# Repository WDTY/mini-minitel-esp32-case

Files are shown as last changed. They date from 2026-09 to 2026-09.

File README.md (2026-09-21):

# Mini Minitel ESP32 case

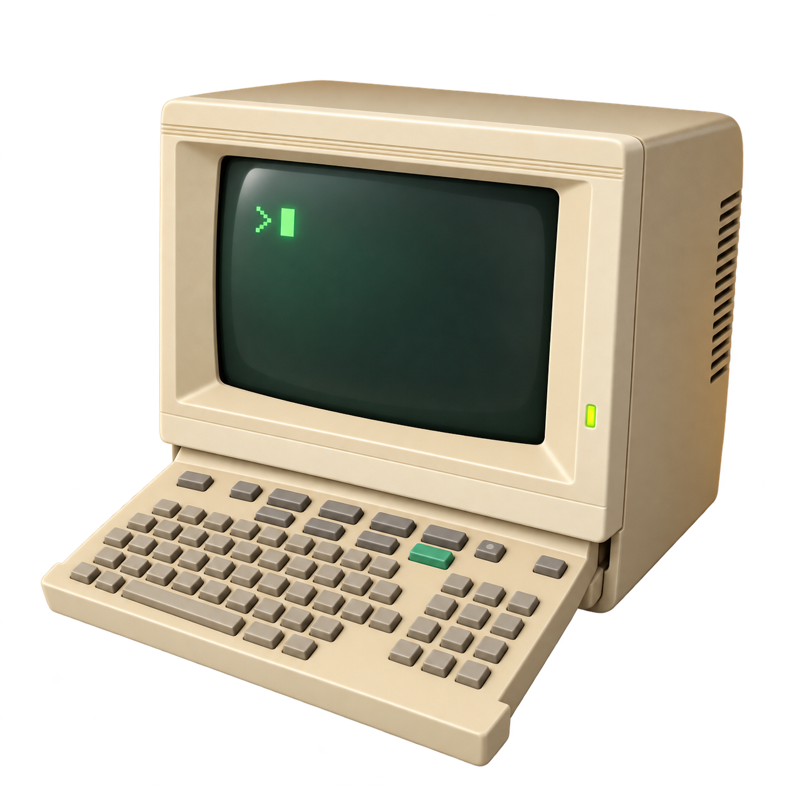
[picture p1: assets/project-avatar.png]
Mini Minitel project avatar


A printable Minitel-shaped enclosure for the
[iodeo ESP Minitel V2](https://github.com/iodeo/Minitel-ESP32) JST cable-to-DIN board.

## Current design: complete three-part v0.5

v0.5 is the complete avatar-inspired miniature Minitel. It prints as three
parts: a hollow cabinet, a separate multicolour keyboard and one removable
ESP32 bay. The external design uses no geometry from the iodeo electronics
enclosure.

Connect JST first, slide the PCB into the bay's edge guides, form the measured
60 mm cable turn and slide the loaded bay into the lower rear of the Minitel.
USB-C and the protruding flexible RESET pad remain accessible at the back. The
DIN plug lays into an open-top notch and never passes through a printed hole.

- [Complete Minitel case STL](stl/v0.5/minitel_case_v0.5.stl)
- [Separate multicolour keyboard STL](stl/v0.5/minitel_keyboard_v0.5.stl)
- [Removable ESP32 bay STL](stl/v0.5/minitel_esp32_bay_v0.5.stl)
- [Dimensions, assembly route, K2 settings and multicolour guide](docs/V0.5-DESIGN.md)
- [Editable OpenSCAD source](src/minitel_v05.scad)

The case is exported flat on its rear. This puts the dark CRT and green
prompt/cursor/lens in the final bounded layers. The keyboard is a separate
flat-bottomed print, so its grey keys and green Enter key do not cause colour
changes throughout the much larger cabinet print.

The CRT face is a shallow compound curve rather than a flat plate. Its centre
bulges forward while the perimeter stays recessed, and the beige inner bezel
funnels inward toward that recessed edge to match the project avatar.

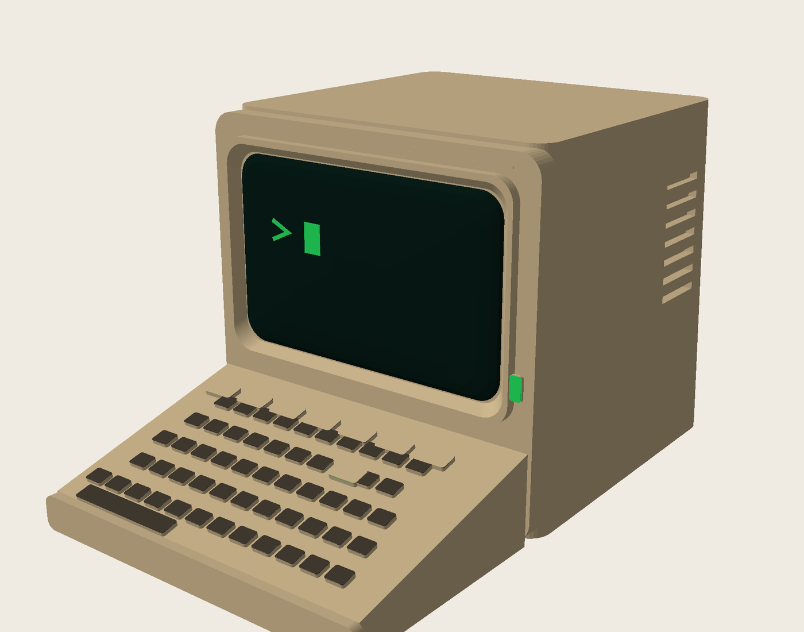
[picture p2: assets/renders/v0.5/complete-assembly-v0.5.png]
Complete multicolour v0.5 assembly

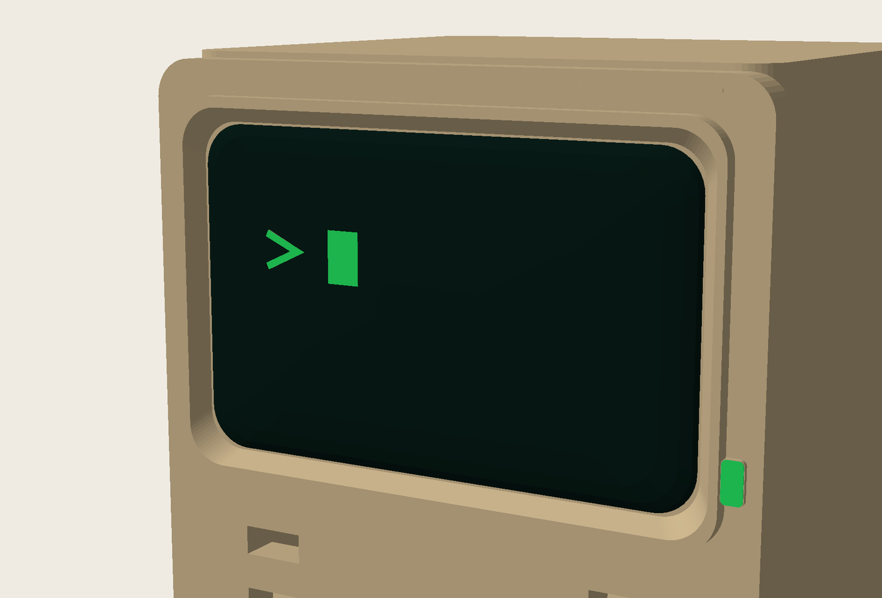
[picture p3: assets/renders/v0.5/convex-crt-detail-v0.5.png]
Convex CRT glass and inward-running bezel

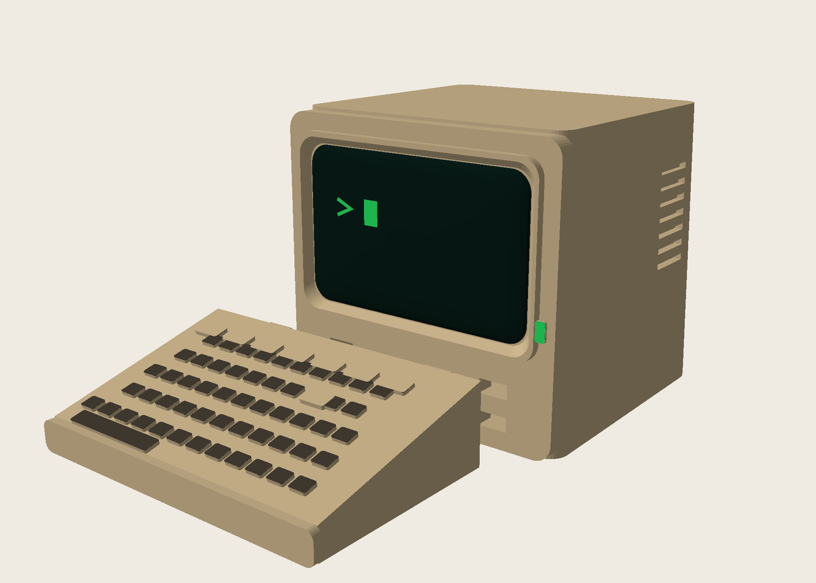
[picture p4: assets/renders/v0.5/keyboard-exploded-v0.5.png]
Separate keyboard and four locating tongues

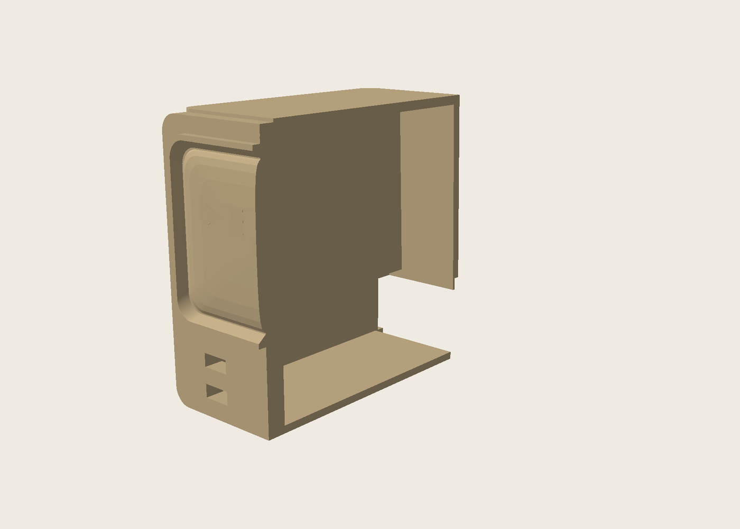
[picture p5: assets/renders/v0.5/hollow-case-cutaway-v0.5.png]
Hollow cabinet, bay guides and print bridge ribs

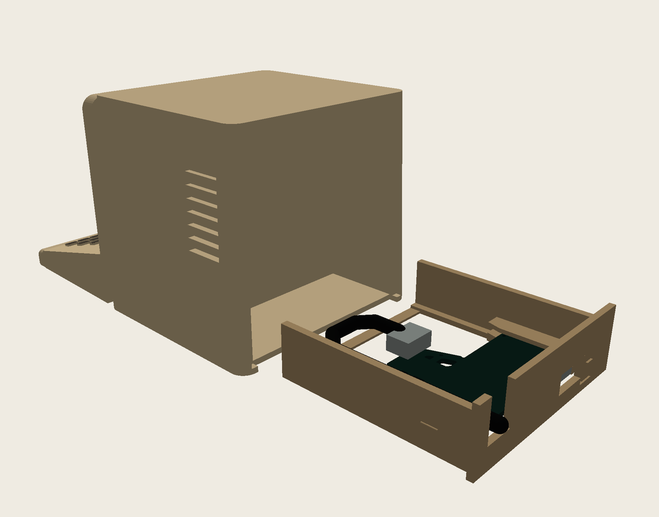
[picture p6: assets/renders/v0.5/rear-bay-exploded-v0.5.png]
Loaded bay behind the lower rear opening

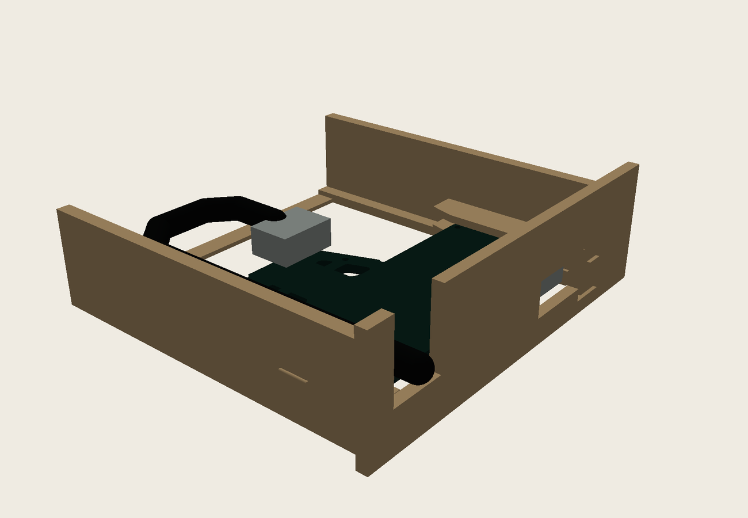
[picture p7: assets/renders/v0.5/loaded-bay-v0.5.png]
ESP32, connected cable and U-turn in the bay

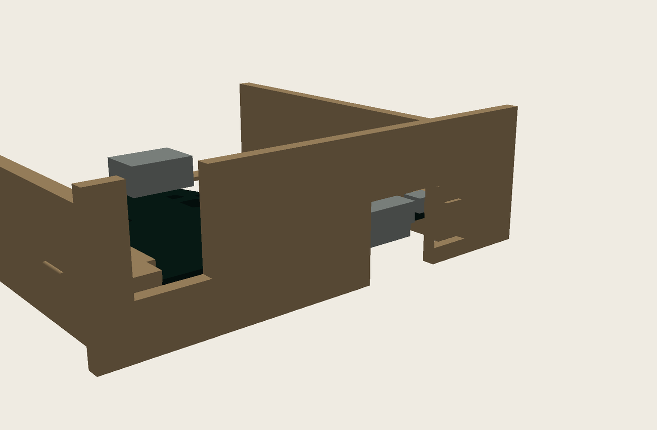
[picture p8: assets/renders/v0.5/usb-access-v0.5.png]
Bottom-open USB-C access at the rear face

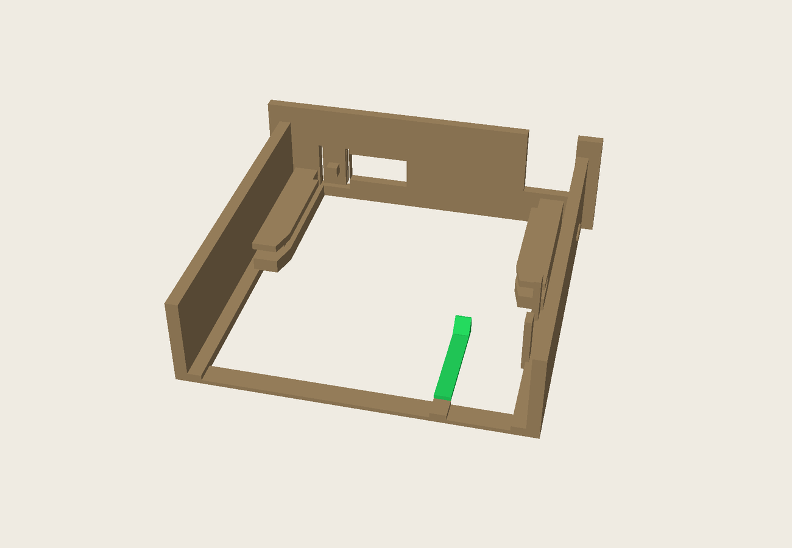
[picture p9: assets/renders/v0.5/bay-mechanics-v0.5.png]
U-rails, front bridge and PCB retention latch


All three parts contain an enclosed `WDTY v0.5` watermark spanning three
0.20 mm layers. The cabinet is a true hollow shell rather than a solid infill
volume. Thin U-guides locate the bay and three permanent 1.2 mm bridge ribs
reduce the rear-down front-wall bridge to 24 mm. The curved CRT backing
overlaps the cabinet by 3.2 mm, so it forms one continuous structure without
a slit.

This remains a mechanical prototype rather than a fully fit-verified release.
A physical ESP Minitel V2 test confirms the PCB/rail fit and cable route. That
test also exposed a USB-C window that sat too high; the rear face now uses a
bottom-open service notch. The bay has a releasable PCB latch, a positive
flange shoulder and open guides for the measured 4.3 mm cable. Those guides
are not hard strain relief. Plug clearance, latch force and RESET travel still
need verification after printing the corrected bay.
See the mechanical audit before printing: a collision-free reference model
alone does not prove physical fit.

## Repository layout

- [`src/`](src/): editable v0.5 OpenSCAD source.
- [`stl/v0.5/`](stl/v0.5/): the three current printable parts.
- [`docs/`](docs/): v0.5 design notes and PCB-reference provenance.
- [`assets/renders/v0.5/`](assets/renders/v0.5/): current CAD renders.
- [`assets/photos/`](assets/photos/): owner-supplied hardware photographs.
- [`reference/`](reference/): PCB inspection mesh and unchanged iodeo references.
- [`tools/`](tools/): Gerber extraction, validation and render scripts.
- [`archive/`](archive/): superseded development files, intentionally omitted
  from this current-version README.

## Editing and exporting

Open [`src/minitel_v05.scad`](src/minitel_v05.scad) in OpenSCAD and select
`case`, `keyboard`, `bay`, `case_assembly` or `assembly` with the `part`
parameter. See the v0.5 design notes for reproducible export, render and
clearance-check commands.

## Attribution and license

Hardware reference: [Louis H./iodeo](https://github.com/iodeo/Minitel-ESP32)
and [Hackaday project](https://hackaday.io/project/180473-minitel-esp32).
This derivative case is licensed under [CC BY-SA 4.0](LICENSE).
Contributions and measured fit reports are welcome.

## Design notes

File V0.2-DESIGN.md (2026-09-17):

# v0.2 proportion study

> Physical-test update: the PCB locating pins and USB-C position do not align
> reliably with the real JST-board. Do not force the PCB or print another v0.2
> body. The corrective design should preserve the printed shell by using a
> separate internal carrier and a shallow inset/snap front.

v0.1 proved the PCB mounting concept, but its `60 x 60 x 34 mm` cabinet and
13 mm keyboard projection read more like an arcade cabinet than an open
Minitel.

The v0.2 work-in-progress uses a new envelope:

| Feature | v0.1 | v0.2 WIP |
| --- | ---: | ---: |
| Cabinet width | 60 mm | 68 mm |
| Cabinet height | 60 mm | 60 mm |
| Cabinet depth | 34 mm | 58 mm |
| Keyboard projection | 13 mm | 38 mm |
| Screen insert | 41 x 22.2 mm | 51.2 x 28.6 mm |

The target is derived independently from owner-supplied photographs and the
published approximate real-machine envelope of `250 x 220 x 260 mm`. The
downloadable Sketchfab reference model was not imported or reused because its
page carries a NoAI restriction.

Research references:

- <https://hackaday.com/2022/02/16/teardown-alcatel-telic-1-minitel-terminal/>
- <https://sketchfab.com/3d-models/minitel-1982-france-864f54ce4e1f41abab0688b88a45babf>
- <https://minitel.us/terminals>

v0.2 was published as a test prototype. Its fit-critical PCB coordinates,
USB-C opening, RESET access and JST cable exit were based on the official iodeo
v2.2 Gerber/drill files and photographs, but the physical test demonstrated
that the coordinate transformation was not reliable enough for the real board.

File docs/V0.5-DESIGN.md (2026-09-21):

# v0.5 complete Minitel case

v0.5 is a complete three-part enclosure for the owner's populated iodeo ESP
Minitel V2 **JST** board. Its exterior follows the project's Minitel avatar;
no geometry from the iodeo electronics enclosure is used.

## Print files

Three current STL files are required:

1. `minitel_case_v0.5.stl` — hollow Minitel cabinet with fixed CRT front,
   vents, bridge ribs and lower rear bay opening; exported on its flat rear.
2. `minitel_keyboard_v0.5.stl` — separate flat-bottomed keyboard, normal keys,
   green Enter-key boundary, front lip and four locating tongues.
3. `minitel_esp32_bay_v0.5.stl` — removable cartridge with PCB edge guides,
   60 mm cable-turn envelope, rear USB-C opening, cable guides, releasable PCB
   latch and flexible reset plunger.

The assembled case measures approximately **78 × 123 × 74 mm**, including the
open keyboard. The bay measures **70 × 66.6 × 21 mm** at its closing flange.
Every part fits comfortably on a Creality K2 build plate.

## Assembly route

1. Push the four keyboard tongues straight into the clearance pockets in the
   lower front of the cabinet. Do not glue this first physical test.
2. Connect the JST plug to the unpowered PCB before putting it in the bay.
3. From the open inner end of the bay, feed the broad USB-C edge into the two
   flared edge guides and slide the board toward the bay's rear face.
4. Lay the cable in a relaxed U: forward from the JST, around the open front of
   the bay and back along the right side. Lay the 4.3 mm cable from above into
   the two outside guides and the open-top rear notch. The 15.5 mm DIN plug
   remains outside and never has to pass through a printed hole.
5. Check that USB-C is centred in its rear opening and that the protruding
   printed reset pad moves freely.
6. The floor cantilever clicks behind the narrow JST-side PCB nose. To remove
   the PCB, press this tab downward with a small plastic tool while sliding the
   board toward the open end.
7. Slide the complete loaded bay into the opening at the lower rear of the
   Minitel until its recessed flange meets the positive cabinet shoulder. The
   shallow side beads provide light retention.

The PCB rests only in 1.0 mm edge channels. There is no snap-on board plate.

## Measured inputs and clearances

| Item | Value |
|---|---:|
| Gerber PCB envelope | 47.105 × 36.218 mm |
| Owner's measured PCB envelope | approximately 46.9 × 36.1 mm |
| Populated height | 10.4 mm |
| Reset protrusion beyond PCB edge | 1.5 mm |
| Black DIN cable diameter | 4.3 mm |
| DIN plug maximum diameter | 15.5 mm |
| PCB thickness | 1.6 mm nominal |
| PCB slot height | 2.2 mm |
| Vertical PCB clearance | 0.30 mm per side |
| Horizontal guide clearance | 0.35 mm per side |
| Case/bay sliding clearance | 0.40 mm per side |
| USB outer edge to outside of relaxed cable bend | 60 mm |
| Bay flange-to-shoulder rest clearance | 0.15 mm |

The route and exit remain open: the printed part guides the measured cable but
does not clamp or sharply bend it. The DIN plug stays outside the enclosure.

## Creality K2 baseline

- 0.4 mm nozzle and fixed 0.20 mm layers.
- PLA for the first print.
- Print all parts in their exported orientation. The case is already rotated
  with its broad rear face on Z=0; do not stand it upright.
- 3 walls, 5 top/bottom layers and 12–15% gyroid infill.
- The hollow cabinet needs no internal infill. Three permanent 1.2 mm ribs
  reduce the final front-wall bridge to 24 mm. Set bridge direction across the
  cabinet width and inspect those layers in preview before printing.
- Keep automatic support disabled inside the hollow cabinet: it would be hard
  to remove through the bay opening. The rear bay opening starts at the plate.
- Keep support out of the PCB guide slots, reset tongue and keyboard pockets.
- Do not scale the models and leave XY/hole compensation at zero for the first
  fit test.
- A brim is normally unnecessary for the rear-down case. A 3–5 mm brim is
  optional for the separate keyboard if its front corners lift.

## Multicolour treatment

STL does not store filament colours. Put the case and keyboard on separate
plates/jobs to avoid unnecessary CFS colour swaps. Use surface painting in
Creality Print or OrcaSlicer:

- Case job: warm beige cabinet, near-black-green CRT, and bright-green prompt,
  cursor and status lens. With the case rear-down these are bounded final
  layers instead of colour changes through the full cabinet height.
- Keyboard job: warm beige deck, dark grey-brown normal keys/spacebar and a
  bright-green Enter key.
- Bay job: cabinet beige or a slightly darker beige, single colour.

All coloured faces are raised or bounded so surface-fill painting can select
them without extra colour STL files.

## Hidden watermark

All three print parts contain an enclosed `WDTY v0.5` void. The void is 0.60 mm
high at Z 0.60–1.20 mm: exactly three layers with the 0.20 mm K2 baseline. It
is invisible from outside and can be found in the slicer's layer preview.
Adaptive layer height changes the layer count, so keep the first 1.4 mm at
0.20 mm when preservation of the three-layer mark matters.

## CAD verification

- All three final STL files are closed, with zero nonmanifold edges.
- The keyboard is checked at its nominal installed position and has no hard
  collision with the cabinet or its four receiver pockets.
- The exact Gerber PCB and approximate component envelopes are sampled at 49
  positions through the PCB-to-bay insertion route.
- The complete loaded bay is sampled at 71 positions through the rear case
  opening. The shallow retention beads are intentionally excluded from the
  hard-collision check because they provide the designed friction contact.
- The routed PCB/component/cable envelopes do not intersect the rigid bay.
- Both lower guide lips overlap the PCB edges by 1 mm; support is checked
  by lowering the reference PCB through the nominal 0.30 mm clearance.
- The reset plunger has 0.30 mm nominal rest clearance to the approximate
  switch envelope and contacts it with 0.50 mm inward travel. This is a rigid
  envelope test, not a flexure or switch-force simulation.
- The floor latch is clear at the installed position and catches the PCB after
  0.70 mm movement toward the open end.
- The bay flange has 0.15 mm rest clearance and contacts the cabinet shoulder
  after 0.20 mm inward overtravel.
- The measured 4.3 mm cable envelope is checked at exactly 60 mm from the
  protruding USB-C edge to the outside of its relaxed U-bend.

## Mechanical audit / revised v0.5

The cabinet is now a hollow 2.0–2.4 mm shell. Thin longitudinal U-guides retain
the bay without a solid tunnel, and three 1.2 mm ribs support the fixed front
when it is printed rear-down. The front fascia overlaps the cabinet by 3.2 mm;
the bezel and CRT surface also have positive overlap, so the screen assembly
cannot become a detached or coplanar shell. Six nested screen profiles form a
shallow compound CRT bulge, while the bezel aperture widens toward the viewer
to create the avatar's inward-running surround. The glass centre remains just
behind the beige bezel face, protecting it during handling.

The original lower guide lips ended outside the PCB. They now extend inward
to match the upper lips, including the flared entrance. The cartridge also has
a four-layer structural front bridge below the underside component envelope,
an accessible PCB retention cantilever and open outside cable guides. The rear
trapezoidal opening is closed above the cartridge, and a two-stage body opening
plus shallow flange recess provides a defined insertion stop. Collision tests
use the complete case rather than only its core and fail on OpenSCAD errors.

Correction to the discussion: there were no duplicated PCB rails in the
case source; that diagnosis resulted from misreading a module boundary.

Physical testing confirms that the ESP Minitel V2 board enters and sits in the
edge guides with its connected JST lead. The first print also showed that the
USB-C connector sat below the enclosed rear window. The corrected design uses
a bottom-open service notch and checks a conservative plug-access envelope.

Remaining unverified constraints: the component envelopes are approximations
and the PCB thickness is nominal. In particular, verify solder joints along
the 1 mm edge-contact strips, USB plug insertion depth, actual switch force/travel,
PLA latch force and cable stiffness before considering this mechanically
validated. The cable guides intentionally do not provide hard strain relief;
do not use either cable to pull the cartridge or PCB. These are prototype
limitations, not passed physical tests or a guaranteed fit.

Rebuild and check from the repository root:

```sh
openscad --export-format binstl -D 'part="case"' -o stl/v0.5/minitel_case_v0.5.stl src/minitel_v05.scad
openscad --export-format binstl -D 'part="keyboard"' -o stl/v0.5/minitel_keyboard_v0.5.stl src/minitel_v05.scad
openscad --export-format binstl -D 'part="bay"' -o stl/v0.5/minitel_esp32_bay_v0.5.stl src/minitel_v05.scad
python3 tools/check_v05_clearance.py
python3 tools/review_v05.py
```

Renders demonstrate the modelled route; the first physical print remains the
authority for filament shrinkage, cable stiffness and tactile-button travel.

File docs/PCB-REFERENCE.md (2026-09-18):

# PCB reference used for v0.3 renders

Source: iodeo/Minitel-ESP32 commit
`39c49b8462b46dfb7da84c08aecdd48e5c52a224`,
[`hardware/Gerber_minitel_esp32_v2.2.zip`](https://github.com/iodeo/Minitel-ESP32/blob/39c49b8462b46dfb7da84c08aecdd48e5c52a224/hardware/Gerber_minitel_esp32_v2.2.zip).
Attribution: Louis H./iodeo, CC BY-SA 4.0.

`tools/build_pcb_reference.py` reads BoardOutline.GKO and the T04 mounting holes in
Drill_NPTH.DRL. It preserves the outer contour and four internal cutouts.
Circular arcs are sampled at at most 0.08 mm along the arc; exported endpoints
are joined within 0.025 mm. This is a sampled CAD reference, not an exact solid
model of the populated board. Gerber extents: 36.220 x 47.105 mm in the chosen
orientation; five nominal 1.143 mm mounting holes. PCB thickness is assumed 1.60 mm.

The orientation is chosen with the connector wing left, the antenna end down
and the USB/reset edge right, based on the upstream 3D view. Position uses the
current carrier parameters: x shift 10 mm, bottom z=6 mm, PCB y=8.80..10.40 mm.
This placement is an inspection hypothesis, not a measured physical fit.

## Findings

The previous rectangular PCB proxy hid the narrow lower section and sloping
shoulders. The replacement carrier now follows the Gerber outer route, supports
all five holes and captures the real top and bottom edges. Its separate legacy
sockets preserve the already printed v0.2 body.

Components, solder joints, connector bodies, cable bending space and button
travel are not reconstructed here. USB-C plug reach and reset operation remain
unverified. The reference also needs dimensional comparison against the owner's
physical JST-equipped board before claiming compatibility.

The complete exterior uses the actual current carrier/lid/keyboard/reset meshes
and the archived v0.2 body, screen and accent inserts.

## Reproduce

Requires Python with NumPy/Pillow, OpenSCAD, and DejaVu Sans for image captions.

```sh
python tools/build_pcb_reference.py /path/to/Gerber_minitel_esp32_v2.2.zip
openscad --export-format binstl -o reference/pcb_reference.stl src/render_reference.scad
python tools/render_v03_readme.py
```

The exploded view moves the board 20 mm forward only for visibility. All images
are software renders of meshes, not generated concept illustrations.

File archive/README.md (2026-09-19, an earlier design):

# Archived prototypes

These versions are retained for reference, not as current print recommendations.

- [v0.1](v0.1/): first experimental meshes and previews.
- [v0.2](v0.2/): historical meshes, renders, design notes and OpenSCAD source.
  Physical testing revealed PCB mounting and service-opening alignment problems.
- [v0.3](v0.3/): attempted v0.2-compatible carrier and lid; fit was not established.
- [v0.4](v0.4/): donor-cassette prototype rejected after the populated JST board
  proved too wide, high and deep for the upstream enclosure.
- [development/v0.5-rear-bay-fixture](development/v0.5-rear-bay-fixture/):
  intermediate open guide fixture used to validate the edge-slot and cable
  routing concept before it was integrated into the complete two-part v0.5.

Each version keeps its source, STL files, renders and version notes together.
The v0.3 and v0.4 sources still import the archived v0.2 body modules.

The v0.2 README is historical documentation; follow the root README for current status.

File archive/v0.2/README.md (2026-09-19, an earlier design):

# Mini Minitel ESP32 case — historical v0.2 documentation

> Archived reference only. See the [current README](../../README.md) for status.

Mini Minitel project avatar

A small, printable Minitel-shaped enclosure for the
[iodeo ESP Minitel V2](https://github.com/iodeo/Minitel-ESP32) board with the
JST cable-to-DIN connector.

The v0.2 test model deliberately follows the project avatar: a rounded CRT
cabinet, recessed dark screen, top ribs, open sloping keyboard, green Enter key
and status light, and cabinet vents on the right side.

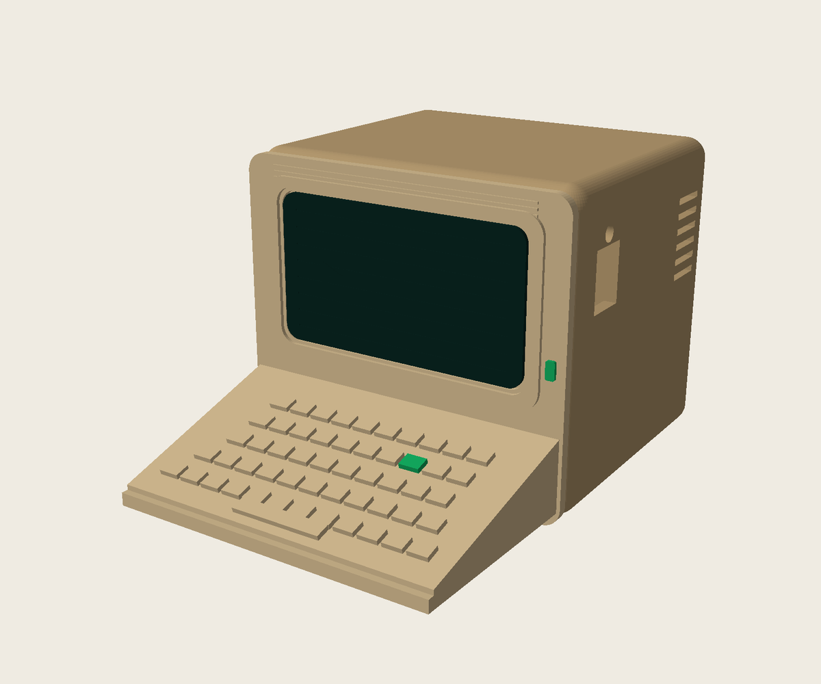
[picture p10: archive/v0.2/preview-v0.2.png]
Three-quarter right-front render of the proportionally rebuilt v0.2 enclosure


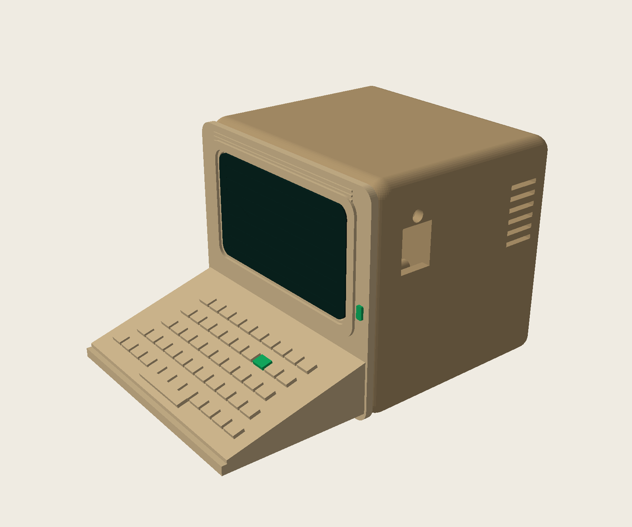
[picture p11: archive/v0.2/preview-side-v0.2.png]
Elevated right-front render showing the deeper CRT cabinet and service openings


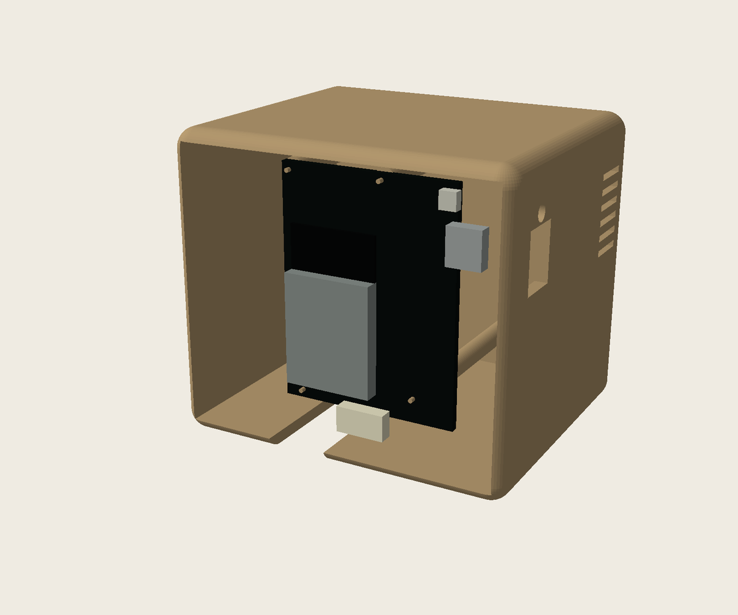
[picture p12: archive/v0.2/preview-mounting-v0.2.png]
Open-front mounting render showing the PCB orientation intended by v0.2


The ESP32 PCB is mounted vertically behind the faux screen. The JST lead exits
through the bottom. USB-C has its own plug-sized side opening and RESET has a
separate protected pinhole. The DIN connector and cable stay outside the
enclosure, so the case does not hang directly from the Minitel port.

## Target hardware

The enclosure targets this JST cable variant. The ruler is included in the
photographs as a practical size reference.

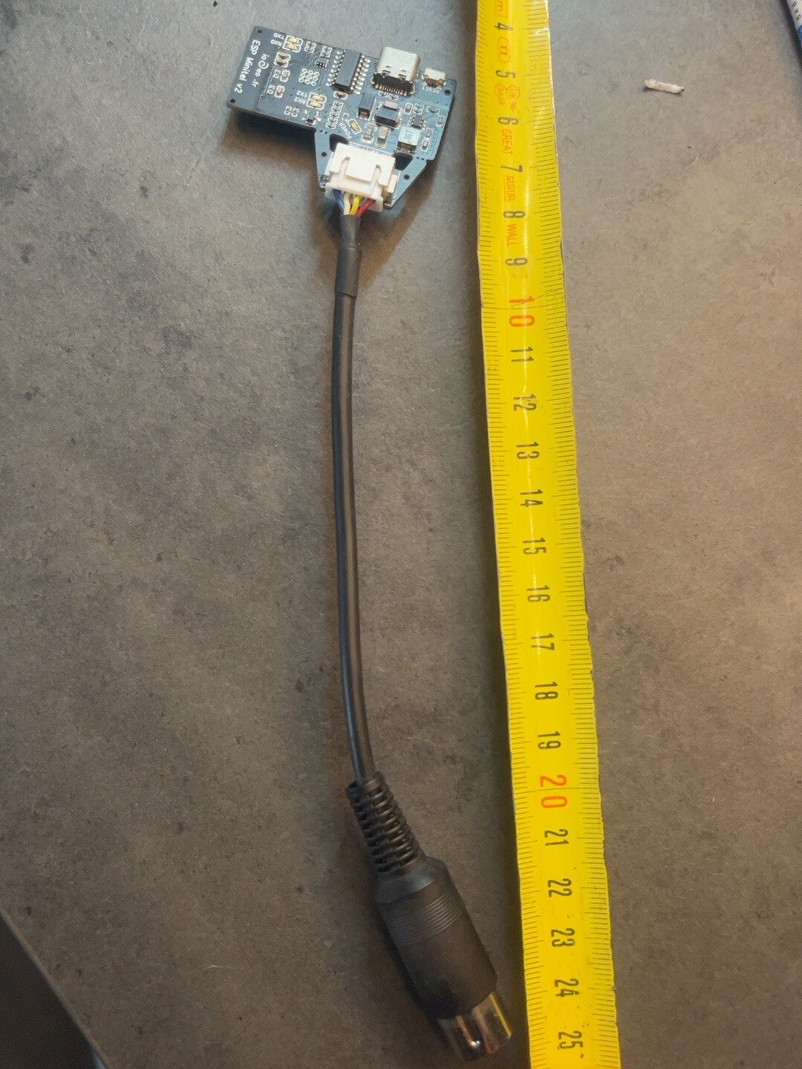
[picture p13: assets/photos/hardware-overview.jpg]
Complete ESP Minitel V2 board, cable and DIN connector


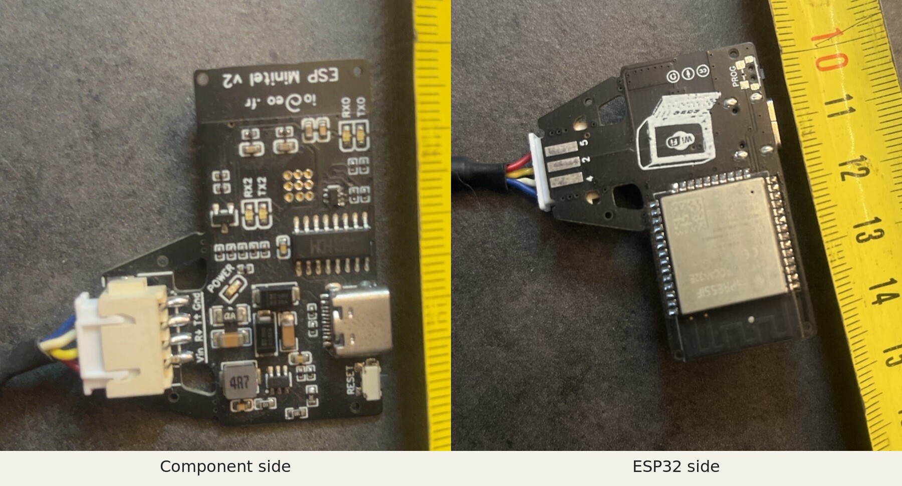
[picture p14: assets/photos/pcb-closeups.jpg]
Component and ESP32 sides of the PCB


> [!WARNING]
> The first physical **v0.2** fit test found that the PCB locating pins do not
> align reliably with the real JST-board and that the fixed USB-C opening cannot
> be reached in the intended centred position. Do not force the PCB and do not
> start a new v0.2 body print. The already printed body is being retained as the
> basis for a corrective clip-in carrier and a support-light inset front.

The first v0.3 compatibility parts are documented in
[`V0.3-COMPAT-DESIGN.md`](../v0.3/V0.3-COMPAT-DESIGN.md). They reuse an existing v0.2
body, shift the PCB on a separate edge cradle, split the front into a shallow
inset lid and removable keyboard, and replace the reset pinhole with a retained
external push button. Treat all v0.3 meshes as fit-test parts until verified on
the physical print.

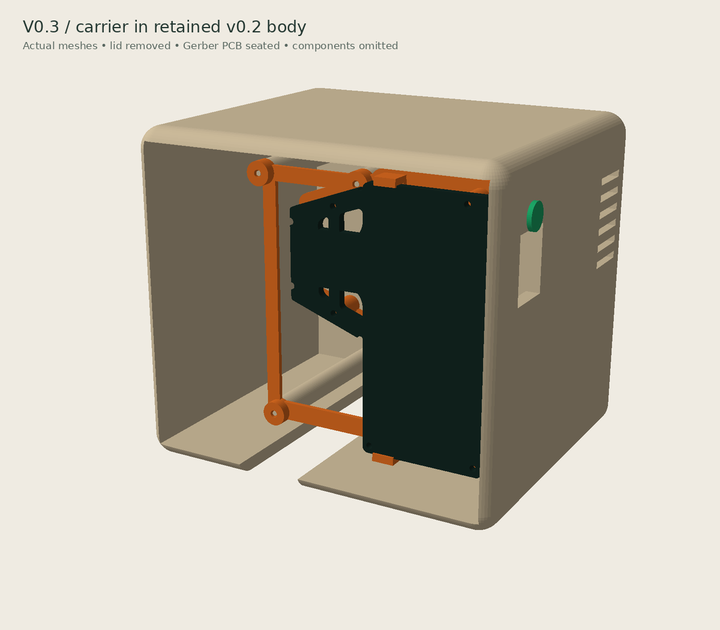
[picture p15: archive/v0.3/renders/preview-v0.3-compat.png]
v0.3 carrier and shifted PCB inside the retained v0.2 body


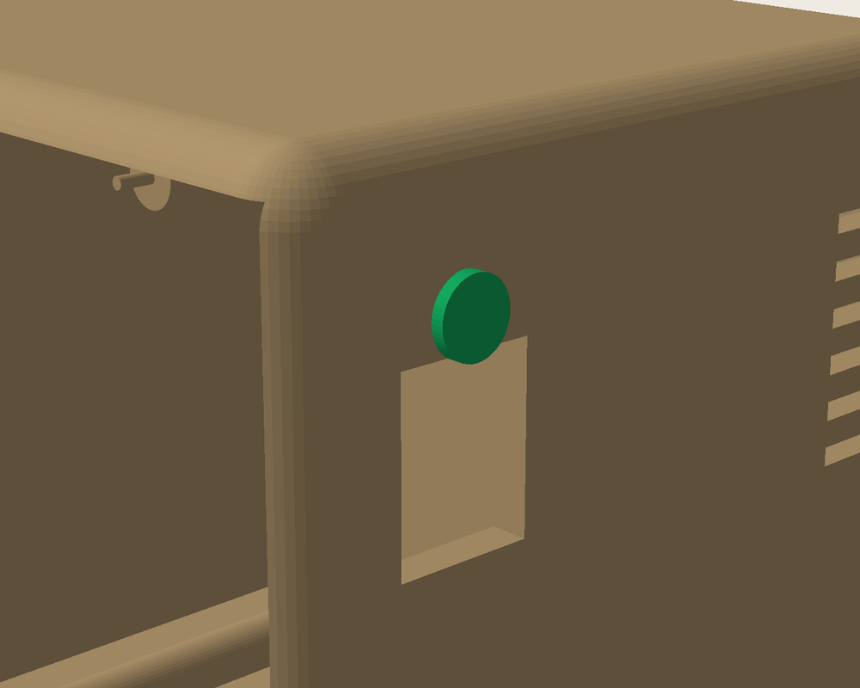
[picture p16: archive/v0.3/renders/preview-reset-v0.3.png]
Close-up render of the protruding retained reset plunger


## Features

- Parametric OpenSCAD source
- Approximately 68 × 60 × 58 mm body, rebuilt from real Minitel proportions
- Rounded CRT bezel and screen insert, top cabinet ribs and side vents
- Sloping open keyboard with a pronounced front lip
- Separate green Enter-key/status-light accent part
- Four PCB locating pins based on the official drill coordinates
- Bottom cable exit
- Separate USB-C opening with clearance for a moulded plug
- Protected RESET pinhole for a paperclip or thin tool
- Simplified printable keyboard and raised terminal-prompt detail
- Two hardware reference images, including a front/back close-up

## Repository layout

```text
archive/v0.2/                 This frozen v0.2 source, meshes and renders
archive/v0.1/                 Archived first prototype
src/                          Current v0.3 OpenSCAD sources
archive/v0.3/stl/             Archived v0.3 test meshes
docs/                         Current design and PCB-reference notes
archive/v0.3/renders/         Archived v0.3 renders
assets/photos/                Hardware overview and PCB close-ups
reference/                    Non-printable PCB inspection mesh
tools/                        Gerber extraction and rendering scripts
LICENSE                       CC BY-SA 4.0 license
```

The v0.2 assembly STL is intended for inspection only. Print the four individual
parts instead. The tiny accent STL is best assigned to green filament as a
multi-part object in OrcaSlicer; it may be omitted for a single-colour print.

## Physical v0.2 fit result

The body-only test was completed on a Creality K2. These checks remain useful
for diagnosing the corrective carrier, but v0.2 should no longer be treated as
a ready-to-print release:

1. Check that the four 0.90 mm locating pins enter the PCB holes.
2. Confirm that no rear-side component touches a support post.
3. Route the JST cable freely through the bottom opening.
4. Insert a USB-C plug fully and confirm that it does not lever against the case.
5. Confirm that RESET can be pressed through its pinhole with a thin tool.

The official drill file specifies nominal 1.143 mm holes and the locating pins
are 0.90 mm. The mismatch is positional rather than a tight-hole problem. Keep
an existing v0.2 body intact until the replacement carrier has been test-fitted.

## Suggested print settings

The model was designed for a Creality K2 with a 0.4 mm nozzle, but it does not
depend on a K2-specific feature.

| Setting | Recommendation |
| --- | --- |
| Material | PLA |
| Layer height | 0.20 mm |
| Walls | 3 |
| Top/bottom layers | 4 |
| Infill | 15% gyroid |
| Supports | Off for body/screen; build-plate-only where needed for front |
| Outer-wall speed | 60–80 mm/s for clean small lettering |

Print the body with its rear surface on the build plate and the cavity facing
up. Print the screen flat. The front may be printed on its side with a brim, or
with the visible side upward and build-plate-only supports beneath the keyboard
deck and rear pins.

## Assembly

1. Remove strings and verify all openings.
2. Place the PCB with the JST connector facing down and USB-C towards the side
   service opening.
3. Guide the cable through the bottom slot.
4. Test the front on the four friction pins. Sand them lightly if needed.
5. Press the screen into its shallow seat. Add a tiny amount of glue only after
   the fit is confirmed.

Only after the body passes this test should you print the v0.2 front, screen
and accent parts.

Classic colours are beige for the body/front and dark green or black for the
screen. The screen is a separate part, so a multi-material system is optional.
The raised terminal prompt can be colour-painted in the slicer.

## Editing and exporting

Open `minitel_esp32_case.scad` in OpenSCAD and select `body`, `front`,
`screen`, `accent` or `assembly` using the `part` parameter. Important
dimensions and fit parameters are grouped at the top of the file.

Increase `fit_clearance` in 0.10 mm steps if the front fixing pins are too
tight. The USB-C and RESET coordinates and opening sizes are also grouped at
the top of the source for easy adjustment after the first body-only fit test.
Do not alter the PCB dimensions until the Gerber dimensions have been compared
with a caliper measurement.

## Attribution and license

Mechanical dimensions were derived from the ESP Minitel V2 open-hardware files
by Louis H./iodeo:

- <https://github.com/iodeo/Minitel-ESP32>
- <https://hackaday.io/project/180473-minitel-esp32>

The upstream hardware is published under CC BY-SA 4.0. This derivative case is
therefore also licensed under the
[Creative Commons Attribution-ShareAlike 4.0 International License](../../LICENSE).

Contributions and real-world fit reports are welcome.

## Version history

- **v0.2 failed fit prototype:** authentic deeper cabinet proportions and a
  much longer fold-down keyboard; physical testing exposed PCB-mount and
  service-opening alignment errors. Existing bodies are candidates for the
  planned corrective carrier and inset front.
- **v0.1 experimental prototype:** first PCB-mounting proof of concept; kept in
  the repository for comparison.

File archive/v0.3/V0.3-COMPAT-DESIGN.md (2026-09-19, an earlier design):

# v0.3 compatibility design

v0.3 is a corrective, test-first upgrade for an already printed v0.2 body.
It deliberately leaves `minitel_body_v0.2.stl` unchanged.

## Design approach

- A separate carrier receives the four legacy v0.2 locating pins. The socket
  bores are re-cut after the connecting ribs are united, so no rib blocks a
  body pin.
- Its inner rail follows the outer route from iodeo's v2.2 Gerber rather than
  assuming a rectangle. Five 3.35 mm support bosses and 0.82 mm tapered nubs
  use the five nominal 1.143 mm PCB holes.
- Flexible hooks at the middle of the top and bottom edges retain the PCB.
  Pressing the board straight onto the nubs moves both hooks outward; they
  return over the front edge when the board is seated.
- The carrier shifts the PCB 10 mm right. The PCB back is at y=10.40 mm,
  leaving 3.40 mm between it and the rear contour rail. This reserves space
  for parts on the USB-C/reset side while keeping both controls within the
  existing side-opening depth range.
- The front is split into a shallow inset lid and a separately printed
  keyboard. Both parts can be oriented with broad, flat faces on the build
  plate and should need substantially less support than `minitel_front_v0.2`.
- A separate reset plunger has a 4.8 mm visible cap, 2.2 mm shaft and shallow
  3.35 mm retaining collar. The cap is intended to project about 1 mm beyond
  the body.

## Test order

1. Print only [`minitel_carrier_v0.3-test.stl`](stl/minitel_carrier_v0.3-test.stl).
   Rotate it so the broad, flat
   rear rail lies on the build plate; the bosses and clips point upward.
2. Slide it over the four existing v0.2 pins without forcing it.
3. Orient the board with the ESP32 module toward the open front/lid and the
   USB-C/reset component side toward the carrier. Align all five holes with
   the tapered nubs and press it in straight until both edge clips return.
4. Verify USB-C, RESET and JST routing before fitting the lid. To remove the
   PCB, move the top and bottom hooks outward gently while lifting the board.
5. Test the reset plunger manually; shorten its inner tip if necessary.
6. Only after the electronics fit, print the lid and keyboard.

## Prototype warning

This is a dimensional recovery prototype based on the v0.2 shell, the official
Gerber and owner-supplied physical-fit photographs. OpenSCAD boolean checks show
no solid overlap between the carrier and unchanged v0.2 body. The upstream
files do not provide reliable component-height solids, so the 3.40 mm rear
clearance, connector alignment and snap force still require the physical test.
Do not glue parts or remove legacy posts. Report tight sockets, clip force and
connector offsets in millimetres before printing the lid.

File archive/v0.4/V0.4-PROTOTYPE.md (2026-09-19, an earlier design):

# v0.4 — rear-entry assessment prototype

This is a geometry-review prototype, not a certified fit or support-free print.
It replaces neither the published v0.3 files nor the user's printed v0.2 body.
The new one-piece outer body requires a new print if adopted.

## Architecture

The official iodeo box is rotated 180 degrees about Z and translated by
[23.75, 58, 10] mm. No scaling, rail edits, or mesh deformation is applied.
The cassette is horizontal, with its end cap at the lower rear. The Minitel
front and keyboard are integrated into the body; there is no large front lid.
An 0.2 mm overlap with the donor's lowest exterior skin connects the box to
the outer floor. The original cap is exported separately in assembly coordinates.
Its opening is at the rear, not the bottom.

The cable slot connects to the rear access opening. It is intentionally loose
and has no validated strain relief. Cable routing above/alongside the cassette,
JST plug clearance through the donor's circular extension, PCB insertion, USB
plug reach, and reset operation all require the owner's physical donor test.
No populated PCB model is supplied: previous PCB placement renders were only
hypotheses, not an established mating transform for this donor.

## Files

- `stl/minitel_body_v0.4-review.stl`: integrated outer body + donor box.
- `stl/minitel_cover_v0.4-review.stl`: rigidly positioned original cap.
- `stl/minitel_assembly_v0.4-review.stl`: visual assembly, NOT a print job.
- The existing v0.2 screen and accent meshes remain cosmetic inserts.

All exports use mm. In the slicer, lay the separate cap on its broad face and
place it on the bed. The body has an enclosed roof and horizontal internal
surfaces; support and its removal must be reviewed. Do not print the full body
until accessibility of required supports has been checked. The rear opening
is intentionally oversized for assessment, not a finished dust-tight closure.

## Verification results

- Body: 22,930 triangles, one connected component, zero nonmanifold edges.
- Cap: 1,064 triangles, one connected component, zero nonmanifold edges.
- Assembly: 24,558 triangles, three connected components, zero nonmanifold edges.
- Body bounds: 68 x 101.6 x 60 mm, including the projecting keyboard.
- Donor input SHA-256 hashes equal the upstream copies byte for byte.
- Cap positions sampled every 1 mm over 20 mm rearward travel have empty
  intersection with the added outer body. This is a sampled test, not continuous
  collision certification.
- The same test against the complete body finds six small interference regions
  at the ORIGINAL donor interface (x +/-19.75, y 59.2..60.2, z 5.3..14.8 mm).
  This may reflect snap-fit retention, but is not confirmed. The cap was not
  modified to hide these overlaps. Await the owner's original-case print test.
- Preview PNGs are software renders of the exported meshes. No PCB or cable
  mesh is presented as a verified installed assembly.

## Attribution and source

Donor files copied unchanged from Louis H./iodeo, Minitel-ESP32,
commit `39c49b8462b46dfb7da84c08aecdd48e5c52a224`,
`hardware/enclosure/box.stl` and `cover.stl`:
https://github.com/iodeo/Minitel-ESP32/tree/39c49b8462b46dfb7da84c08aecdd48e5c52a224/hardware/enclosure

Upstream declares the dev board CC BY-SA 4.0; this derivative is shared under
the repository's CC BY-SA 4.0 license with this attribution retained.

## Rebuild

From repository root:

```sh
openscad --export-format binstl -D 'part="body"' -o archive/v0.4/stl/minitel_body_v0.4-review.stl archive/v0.4/src/minitel_v04.scad
openscad --export-format binstl -D 'part="cover"' -o archive/v0.4/stl/minitel_cover_v0.4-review.stl archive/v0.4/src/minitel_v04.scad
openscad --export-format binstl -D 'part="assembly"' -o archive/v0.4/stl/minitel_assembly_v0.4-review.stl archive/v0.4/src/minitel_v04.scad
```

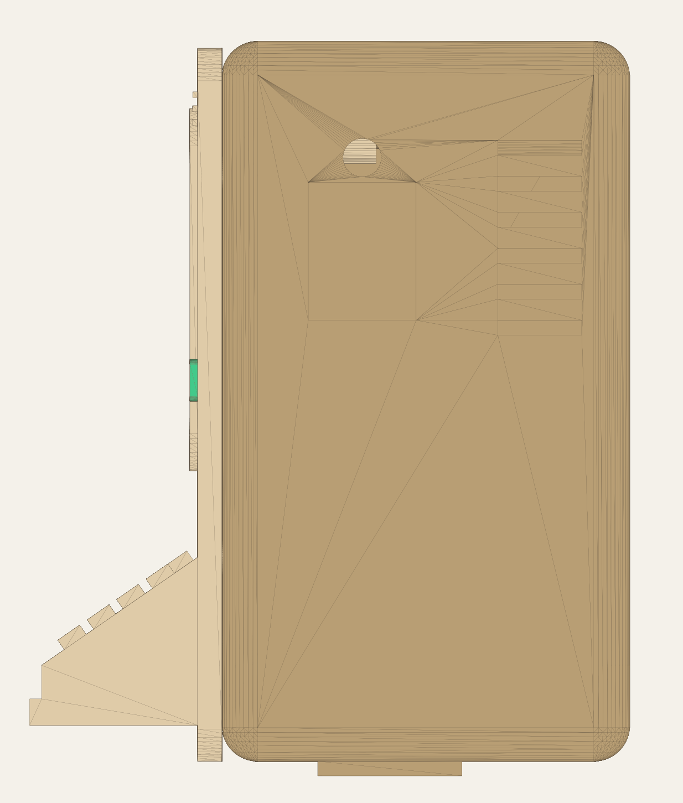
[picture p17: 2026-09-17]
preview-side.png

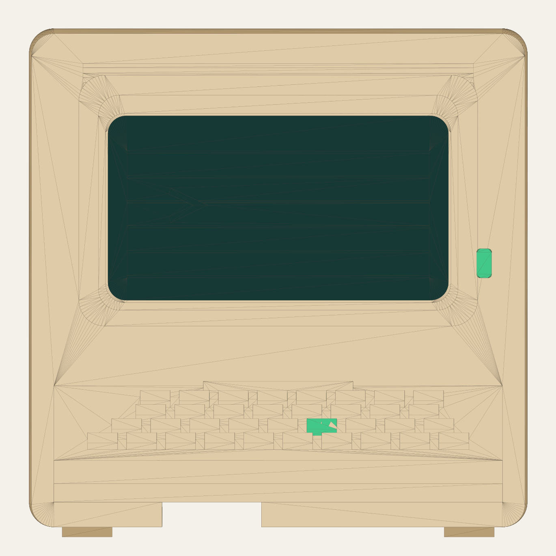
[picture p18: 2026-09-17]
preview.png

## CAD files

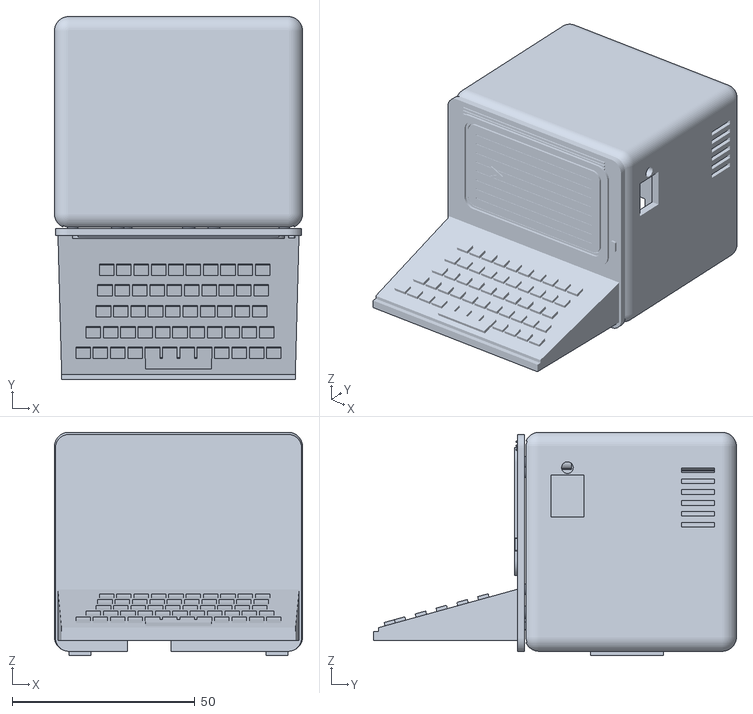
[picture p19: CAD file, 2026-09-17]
minitel_assembly_v0.2.stl
68.0 x 99.4 x 61.2

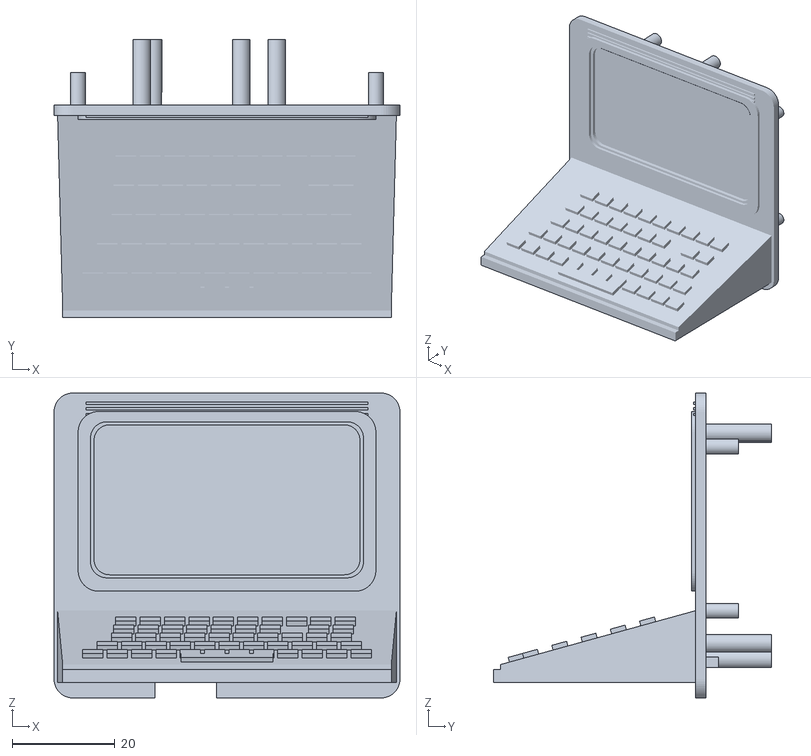
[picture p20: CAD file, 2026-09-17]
minitel_front_v0.2.stl
67.4 x 54.2 x 59.4

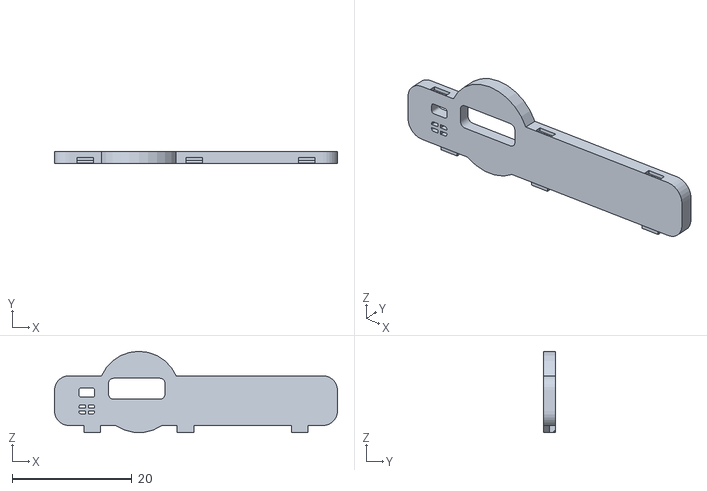
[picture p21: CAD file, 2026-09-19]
reference/iodeo-enclosure/cover.stl
47.3 x 2.00 x 13.6

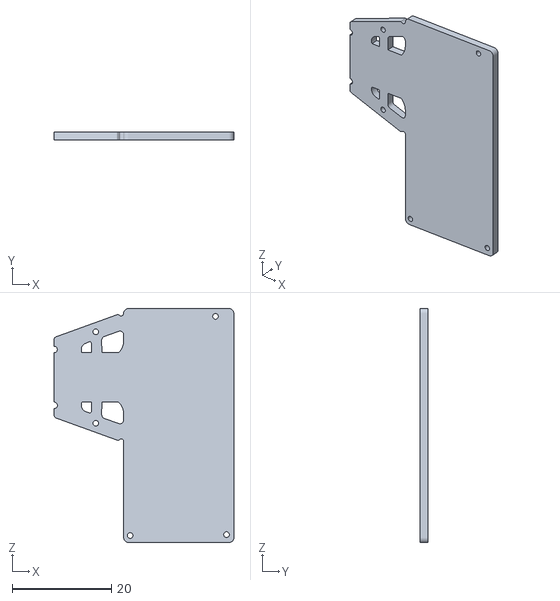
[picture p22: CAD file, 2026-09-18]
reference/pcb_reference.stl
36.2 x 1.60 x 47.1

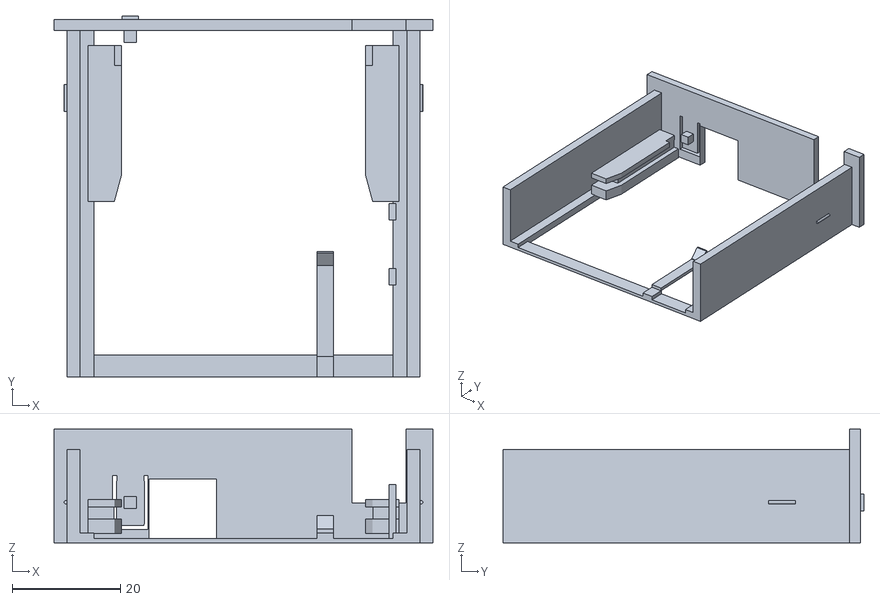
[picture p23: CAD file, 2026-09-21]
stl/v0.5/minitel_esp32_bay_v0.5.stl
70.0 x 66.6 x 21.0

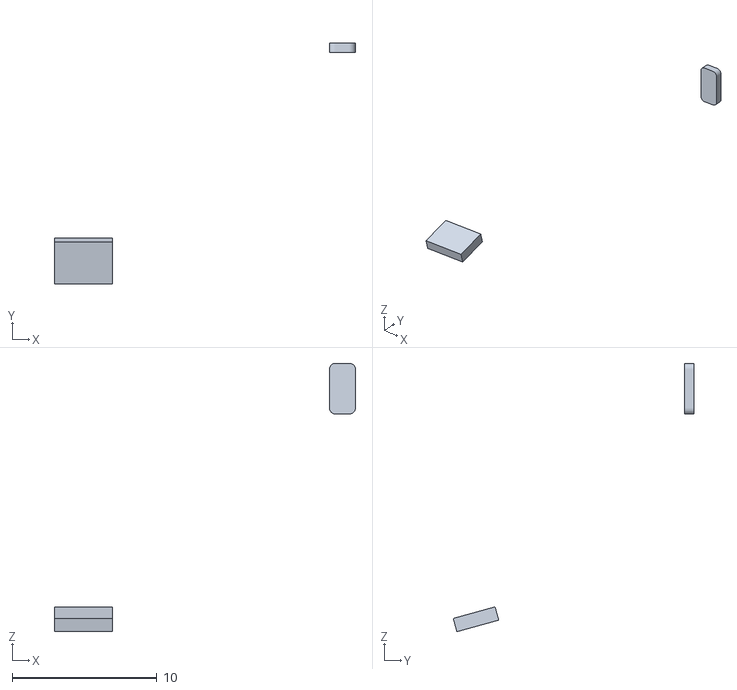
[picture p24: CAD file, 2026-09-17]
minitel_accent_v0.2.stl
20.8 x 16.6 x 18.5

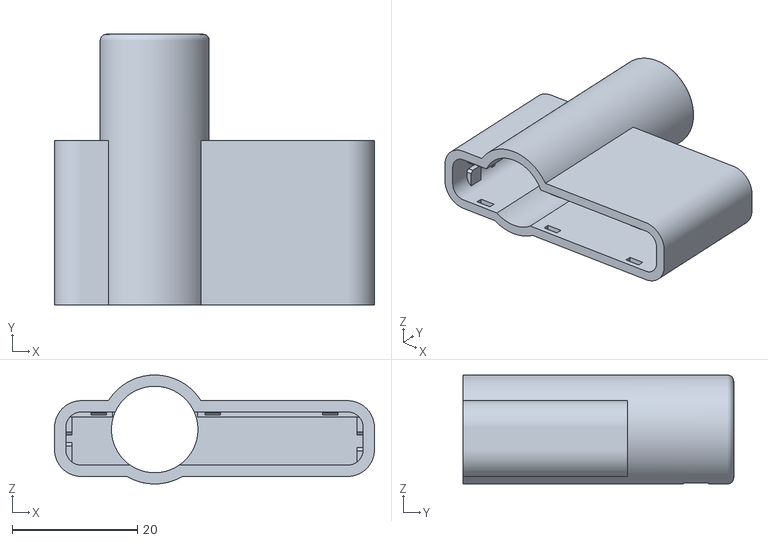
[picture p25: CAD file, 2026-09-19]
reference/iodeo-enclosure/box.stl
51.1 x 43.2 x 17.4

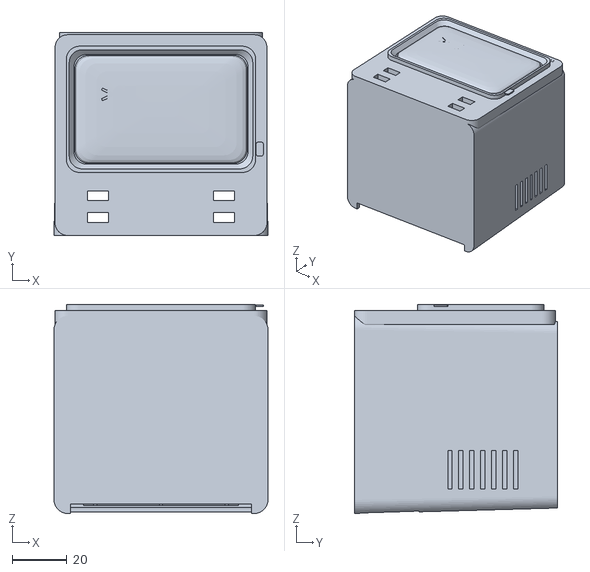
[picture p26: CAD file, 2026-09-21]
stl/v0.5/minitel_case_v0.5.stl
78.0 x 74.0 x 76.2

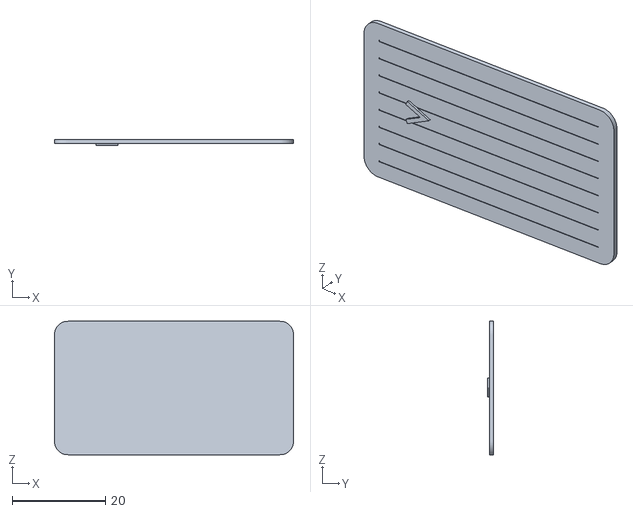
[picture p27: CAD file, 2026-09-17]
minitel_screen_v0.2.stl
51.2 x 1.21 x 28.6

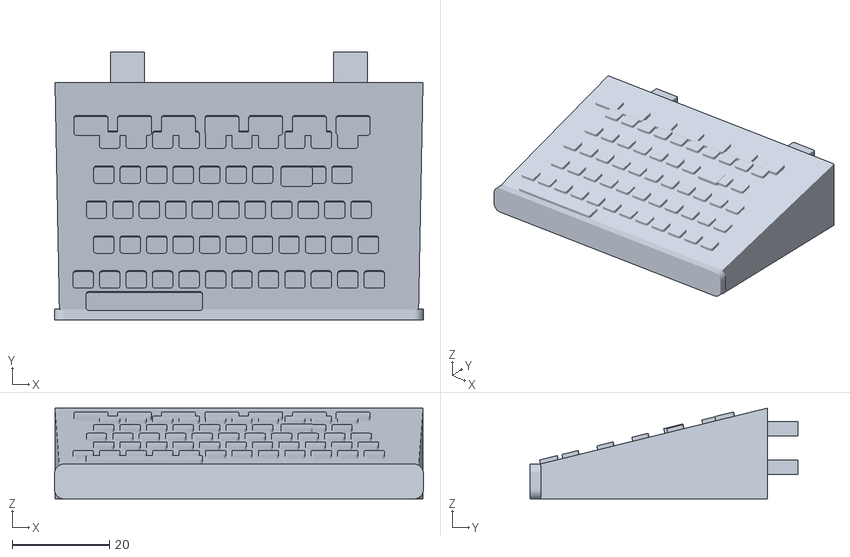
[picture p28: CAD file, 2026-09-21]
stl/v0.5/minitel_keyboard_v0.5.stl
76.0 x 55.1 x 18.7

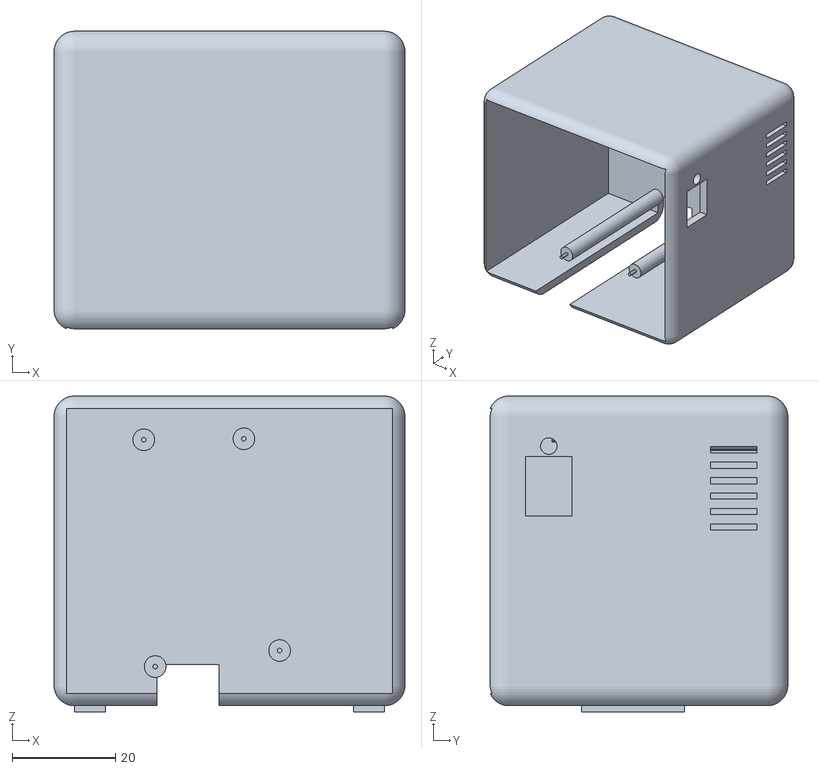
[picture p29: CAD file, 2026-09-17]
minitel_body_v0.2.stl
68.0 x 57.6 x 61.2

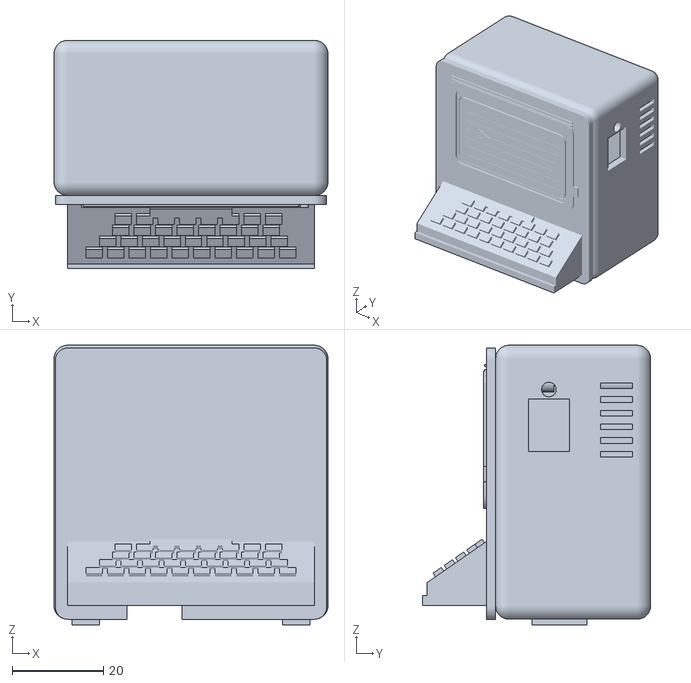
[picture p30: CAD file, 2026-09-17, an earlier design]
archive/v0.1/minitel_assembly_v0.1.stl
60.0 x 50.0 x 61.2

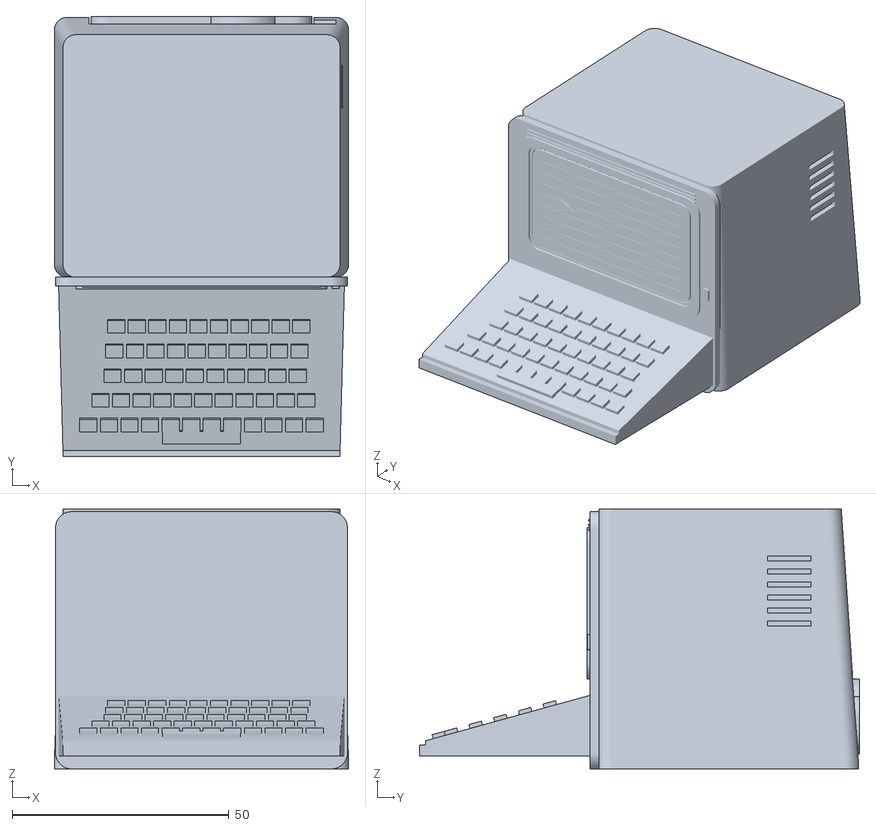
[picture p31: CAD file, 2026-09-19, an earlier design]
archive/v0.4/stl/minitel_assembly_v0.4-review.stl
68.0 x 101.6 x 60.0

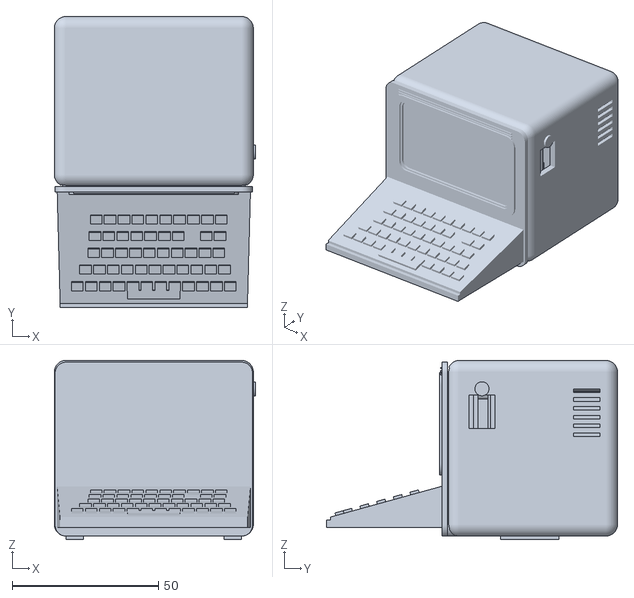
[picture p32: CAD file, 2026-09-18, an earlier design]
archive/v0.3/stl/minitel_assembly_v0.3-test.stl
68.8 x 99.4 x 61.2

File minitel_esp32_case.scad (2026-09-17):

/*
  Mini Minitel enclosure for the iodeo ESP Minitel V2 JST/cable board.

  v0.2 work-in-progress: proportions rebuilt from the approximately
  250 x 220 x 260 mm real Minitel envelope and the owner's photographs.

  Board geometry is based on the official v2.2 Gerber outline and mounting
  holes, checked against photographs of the actual board.

  Select one of: "body", "front", "screen", "accent", "assembly".
  License: CC BY-SA 4.0. See README.md and LICENSE.txt.
*/

part = "assembly"; // [body, front, screen, accent, assembly]
$fn = 48;

// Printer-fit parameters. Increase fit_clearance in 0.10 mm steps if needed.
fit_clearance = 0.25;
wall = 2.4;

// Main enclosure dimensions.
body_w = 68;
body_d = 58;
body_h = 60;
corner_r = 4.0;

// Official Gerber board extents, rotated so the JST lead points down.
pcb_w = 36.22;
pcb_h = 47.10;
pcb_t = 1.60;
pcb_bottom_z = 6.0;
pcb_plane_y = 14.0;

// Side controls, measured from the PCB photographs and deliberately exposed
// as fit-test parameters. Coordinates are in enclosure space after rotating
// the PCB so the JST lead points down.
usb_c_y = 11.7;
usb_c_z = 42.5;
usb_c_depth = 9.0;
usb_c_height = 11.5;
reset_y = 11.7;
reset_z = 50.3;
reset_access_d = 3.2;

// Non-plated mounting holes from the v2.2 drill file, after rotation and
// normalization. Coordinates are [x from PCB center, z from PCB bottom].
pcb_holes = [
    [-16.61, 45.51],
    [  2.79, 45.71],
    [-14.39,  1.60],
    [  9.71,  4.70],
    [  9.71, 23.10]
];

// Four holes give stable support; the fifth remains unobstructed.
mount_holes = [0, 1, 2, 3];

module rounded_box(w, d, h, r) {
    translate([-w/2 + r, r, r])
        minkowski() {
            cube([w - 2*r, d - 2*r, h - 2*r]);
            sphere(r=r);
        }
}

module rounded_plate_xz(w, h, d, r) {
    // Front surface at y=-d, back surface at y=0.
    translate([0, 0, h/2])
        rotate([90, 0, 0])
            linear_extrude(height=d)
                offset(r=r)
                    square([w - 2*r, h - 2*r], center=true);
}

module y_cylinder(x, z, y_front, y_back, diameter) {
    translate([x, y_back, z])
        rotate([90, 0, 0])
            cylinder(h=y_back-y_front, d=diameter);
}

module x_cylinder(y, z, x_left, x_right, diameter) {
    translate([x_left, y, z])
        rotate([0, 90, 0])
            cylinder(h=x_right-x_left, d=diameter);
}

module side_service_openings() {
    // USB-C: enough room for the metal receptacle plus a normal moulded plug.
    // This is intentionally rectangular for support-free printing on the rear.
    translate([body_w/2 - wall - 0.5,
               usb_c_y - usb_c_depth/2,
               usb_c_z - usb_c_height/2])
        cube([wall + 2, usb_c_depth, usb_c_height]);

    // RESET: a narrow guided access hole for a paperclip or 2 mm pin. The
    // button remains protected from accidental presses.
    x_cylinder(reset_y, reset_z,
               body_w/2 - wall - 0.5,
               body_w/2 + 1.5,
               reset_access_d);
}

module side_vents() {
    // Rearward horizontal slots echo the original Minitel cabinet while
    // staying clear of USB-C and RESET nearer the front of the right wall.
    for (z = [34.0:3.0:49.0])
        translate([body_w/2 - wall - 0.5, 43.0, z])
            cube([wall + 2, 9.0, 1.25]);
}

module front_fixing_holes() {
    for (x = [-29, 29], z = [17, 49])
        y_cylinder(x, z, -0.3, 7.0, 3.0 + 2*fit_clearance);
}

module board_mounts() {
    inner_back_y = body_d - wall;
    pcb_back_y = pcb_plane_y + pcb_t/2;

    for (i = mount_holes) {
        p = pcb_holes[i];
        x = p[0];
        z = pcb_bottom_z + p[1];

        // Broad support from the rear wall up to the back of the PCB.
        y_cylinder(x, z, pcb_back_y, inner_back_y + 0.1, 4.2);

        // 0.90 mm locating pin for the nominal 1.143 mm PCB hole.
        y_cylinder(x, z, pcb_plane_y - 1.7, pcb_back_y + 0.15, 0.90);
    }
}

module body() {
    union() {
        difference() {
            rounded_box(body_w, body_d, body_h, corner_r);

            // Front-open cavity. The retained rim is the mounting face.
            translate([-body_w/2 + wall, -1, wall])
                cube([body_w - 2*wall,
                      body_d - wall + 1,
                      body_h - 2*wall]);

            // Separate right-side access for USB-C and the protected RESET.
            side_service_openings();

            side_vents();

            // Bottom cable exit for the JST lead; open to the front for assembly.
            translate([-14.0, -1.0, -1.0])
                cube([12.0, body_d + 2.0, 9.0]);

            front_fixing_holes();
        }

        // Add these after hollowing so they remain inside the cavity.
        board_mounts();

        // Small feet keep the cable exit from being pinched on a desk.
        for (x = [-27, 27])
            translate([x-3, 18, -1.2]) cube([6, 20, 1.4]);
    }
}

module keyboard_wedge() {
    // The real Minitel keyboard projects far forward when opened. Keeping
    // this depth near 56% of the body width fixes v0.1's arcade-cabinet look.
    polyhedron(
        points=[
            [-33,-2, 3], [33,-2, 3], [32,-40,3], [-32,-40,3],
            [-33,-2,17], [33,-2,17], [32,-40,6.5], [-32,-40,6.5]
        ],
        faces=[
            [0,1,2,3], [4,7,6,5], [0,4,5,1],
            [1,5,6,2], [2,6,7,3], [3,7,4,0]
        ]
    );
}

function keyboard_z(y) = 6.5 + (y + 40) * (10.5/38);

module keycap(x, y, w=3.6, d=2.2) {
    key_angle = atan(10.5/38);
    translate([x, y, keyboard_z(y)])
        rotate([key_angle, 0, 0])
            translate([-w/2, -d/2, -0.20])
                cube([w, d, 1.15]);
}

module keyboard_keys() {
    // Five well-separated rows fill the opened deck like the real keyboard.
    for (row = [0:4]) {
        y = -34.0 + row*5.7;
        count = row == 0 ? 12 : (row == 1 ? 11 : 10);
        spacing = 4.75;
        shift = row*0.42;
        for (col = [0:count-1]) {
            x = (col-(count-1)/2)*spacing + shift;
            // Leave one position open for the separately coloured Enter key.
            if (!(row == 3 && col == 7)) keycap(x, y, 4.0, 3.0);
        }
    }
    keycap(0, -36.8, 18, 3.0);
}

module keyboard_front_lip() {
    // The rolled front edge gives the open keyboard the toy-like silhouette
    // used by the project avatar and the full-size reference Minitel.
    translate([-32, -41.4, 3.0]) cube([64, 1.8, 2.5]);
}

module screen_bezel() {
    // Raised rounded CRT surround around the removable screen insert.
    difference() {
        translate([0, -1.90, 20.8])
            rounded_plate_xz(58.0, 35.0, 0.85, 4.0);
        translate([0, -1.80, 23.4])
            rounded_plate_xz(53.2, 30.4, 1.9, 3.2);
    }
}

module top_ribs() {
    // Three fine horizontal cabinet ribs from the photographed Minitel.
    for (z = [55.0, 56.10, 57.20])
        translate([-27.5, -2.42, z]) cube([55.0, 0.50, 0.45]);
}

module front_retainer_posts() {
    // These stop the PCB lifting off its locating pins. A 0.35 mm nominal
    // gap avoids squeezing the board when the front is fitted.
    target_y = pcb_plane_y - pcb_t/2 - 0.35;
    for (i = mount_holes) {
        p = pcb_holes[i];
        x = p[0];
        z = pcb_bottom_z + p[1];
        y_cylinder(x, z, 0, target_y, 3.4);
    }
}

module front_fixing_pins() {
    for (x = [-29, 29], z = [17, 49])
        y_cylinder(x, z, 0, 6.4, 2.90);
}

module minitel_label() {
    translate([-13.5, -1.95, 20.1])
        rotate([90, 0, 0])
            linear_extrude(height=0.65)
                text("MINITEL", size=4.3,
                     font="Liberation Sans:style=Bold",
                     halign="left", valign="bottom");
}

module front() {
    difference() {
        union() {
            rounded_plate_xz(body_w-0.6, body_h-0.6, 2.0, corner_r-0.3);
            screen_bezel();
            top_ribs();
            keyboard_wedge();
            keyboard_keys();
            keyboard_front_lip();
            front_fixing_pins();
            front_retainer_posts();
        }

        // Rounded 0.9 mm-deep seat for the separately printable CRT insert.
        translate([0, -1.10, 24.0])
            rounded_plate_xz(51.8, 29.2, 1.05, 3.0);

        // Continue the JST cable notch through the front rim/deck rear.
        translate([-14.0, -2.5, -1.0])
            cube([12.0, 5.0, 9.0]);
    }
}

module screen() {
    difference() {
        translate([0, -1.42, 24.3])
            rounded_plate_xz(51.2, 28.6, 0.82, 2.85);

        // Subtle horizontal scan-line grooves.
        for (z = [27.2:3.2:49.6])
            translate([-22.5, -2.30, z])
                cube([45.0, 0.18, 0.28]);
    }

    // Small terminal prompt matching the avatar, readable at thumbnail scale.
    translate([-17.0, -2.18, 36.0])
        rotate([90, 0, 0])
            linear_extrude(height=0.45)
                text(">", size=6.2,
                     font="Liberation Mono:style=Bold",
                     halign="left", valign="bottom");
}
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

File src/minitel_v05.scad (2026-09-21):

/*
  Mini Minitel ESP32 case v0.5

  Complete avatar-inspired Minitel enclosure plus one removable rear bay for
  the populated iodeo ESP Minitel V2 JST board. The iodeo enclosure geometry
  is deliberately not used. Units: mm.

  Creality K2 baseline: 0.4 mm nozzle, 0.20 mm layers, PLA.
  Select: case, case_assembly, keyboard, bay, assembly, pcb, cable,
          keyboard_case_interference, case_bay_interference,
          pcb_insertion_interference, bay_route_interference.
*/

include <pcb_reference.scad>

part = "assembly";
sweep_offset = 0;
$fn = 40;

// ----- Printer and measured hardware -----
layer_h = 0.20;
wall = 2.40;
sliding_clearance = 0.40;       // each side, K2/PLA baseline
pcb_length = 47.10521;
pcb_depth = 36.21792;
pcb_thickness = 1.60;
populated_height = 10.40;
pcb_slot_h = 2.20;              // 0.30 mm above/below nominal PCB
pcb_side_clearance = 0.35;
edge_capture = 1.00;
cable_d = 4.30;                 // measured black DIN lead
din_plug_d = 15.50;             // measured; plug remains outside the bay
reset_protrusion = 1.50;        // measured beyond the PCB rear edge

watermark_text = "WDTY v0.5";
watermark_z = 0.60;
watermark_h = 0.60;             // three 0.20 mm layers

// ----- Complete miniature Minitel envelope -----
case_w = 78.0;
case_d = 72.0;
case_h = 74.0;
case_corner = 5.0;
case_top_inset = 2.0;

// The keyboard is a separate, flat-bottomed multicolour print. Four rigid
// tongues locate it in clearance pockets in the lower front of the cabinet.
// The 0.30 mm per-face clearance is deliberately conservative for K2/PLA.
keyboard_seam_y = -2.20;
keyboard_tab_w = 7.0;
keyboard_tab_d = 7.0;
keyboard_tab_h = 3.0;
keyboard_tab_clearance = 0.30;
keyboard_tab_x = [-23.0,23.0];
keyboard_tab_z = [5.0,13.0];

// Bay is assembled outside the case and inserted from the lower rear.
bay_w = 65.2;
bay_d = 66.0;
bay_floor_h = 1.80;
bay_body_h = 17.2;
bay_flange_w = 70.0;
bay_flange_h = 21.0;
bay_flange_t = 2.0;
bay_flange_recess_d = 2.25;
bay_stop_clearance = 0.15;
bay_installed_y = case_d - bay_d - bay_flange_recess_d
                  + bay_flange_t + bay_stop_clearance;
bay_installed_z = 2.20;
bay_opening_w = bay_w + 2*sliding_clearance;
bay_opening_h = bay_body_h + 0.80;

// Board orientation inside the bay: JST points toward the front/loop and the
// USB-C/RESET edge finishes at the rear service face.
pcb_rear_y = 60.0;
usb_outer_y = 64.0;
// Owner measured 60 mm from protruding USB-C to the outside of the relaxed
// cable bend, not to its centreline.
loop_depth = 60.0;
loop_front_y = usb_outer_y - loop_depth + cable_d/2;
pcb_z = 4.70;
slot_bottom_z = pcb_z - (pcb_slot_h-pcb_thickness)/2;
slot_top_z = slot_bottom_z + pcb_slot_h;
board_edge_x = pcb_length/2;
slot_wall_x = board_edge_x + pcb_side_clearance;
lip_inner_x = board_edge_x - edge_capture;
rail_outer_x = 28.70;
rail_front_y = 37.40;
rail_rear_y = 61.20;
rail_mouth_y = 32.60;
rail_top_z = 8.00;
cable_z = rail_top_z + cable_d/2 + 0.35;

// Approximate component positions only constrain insertion and service access.
usb_x0 = -15.5;
usb_x1 = -7.0;
// The physical v2 board sits lower than the first component mock suggested.
// Keep the proven horizontal alignment, but make the service opening a
// bottom-open notch so the USB-C shell and moulded plug can never disappear
// behind a printed lower lip.
usb_access_z1 = 11.8;
reset_x = -20.9;
reset_z = pcb_z + pcb_thickness + 1.15;

// Accessible floor cantilever that clicks behind the narrow JST-side nose.
pcb_latch_x = 15.1;
pcb_latch_tip_y = 23.20;
pcb_latch_w = 3.0;
pcb_latch_t = 0.80;
pcb_latch_hook_z = pcb_z + 0.35;

module rounded_rect_2d(w,h,r) {
    offset(r=r) square([w-2*r,h-2*r],center=true);
}

module rounded_xy(w,d,h,r) {
    linear_extrude(height=h) rounded_rect_2d(w,d,r);
}

module rounded_xz(w,h,d,r) {
    translate([0,0,h/2]) rotate([90,0,0])
        linear_extrude(height=d) rounded_rect_2d(w,h,r);
}

module cabinet_outer() {
    // Gentle taper and deep CRT cabinet, matching the project avatar.
    hull() {
        translate([0,case_d/2,0]) rounded_xy(case_w,case_d,2.0,case_corner);
        translate([0,case_d/2,case_h-2.0])
            rounded_xy(case_w-2*case_top_inset,
                       case_d-2*case_top_inset,2.0,case_corner-0.8);
    }
}

module cabinet_inner() {
    // True hollow envelope. The slightly thinner 2.0 mm lower skin gives the
    // installed bay 0.20 mm floor clearance; all other walls remain 2.4 mm.
    hull() {
        translate([0,case_d/2,2.0])
            rounded_xy(case_w-2*wall,case_d-2*wall,2.0,
                       case_corner-wall/2);
        translate([0,case_d/2,case_h-wall-2.0])
            rounded_xy(case_w-2*case_top_inset-2*wall,
                       case_d-2*case_top_inset-2*wall,2.0,
                       case_corner-1.0-wall/2);
    }
}

module keyboard_wedge() {
    // Open-Minitel proportions: almost as wide as the cabinet and visibly
    // deeper than the screen body, as in the avatar.
    polyhedron(
        points=[
            [-38, 3,0], [38, 3,0], [37,-49,0], [-37,-49,0],
            [-38, 3,20], [38, 3,20], [37,-49,7.2], [-37,-49,7.2]
        ],
        faces=[
            [0,3,2,1], [4,5,6,7], [0,1,5,4],
            [1,2,6,5], [2,3,7,6], [3,0,4,7]
        ]
    );
}

function key_z(y) = 7.2 + (y+49)*(12.8/52);
key_angle = atan(12.8/52);

module keycap(x,y,w=4.2,d=3.5,h=1.0) {
    translate([x,y,key_z(y)]) rotate([key_angle,0,0])
        translate([-w/2,-d/2,-0.15])
            linear_extrude(height=h) offset(r=0.55)
                square([w-1.1,d-1.1],center=true);
}

module keyboard_keys_grey() {
    // Avatar-style dense keyboard. Raised top faces are easy to paint by
    // surface in Creality Print/Orca while remaining one case STL.
    for (row=[0:4]) {
        y = -41.0 + row*7.2;
        count = row==0 ? 12 : (row==1 ? 11 : (row==2 ? 11 : 10));
        spacing = 5.45;
        shift = row==1 ? 1.5 : (row==3 ? -1.2 : 0);
        for (col=[0:count-1]) {
            x=(col-(count-1)/2)*spacing+shift;
            if (!(row==3 && col==7)) keycap(x,y);
        }
    }
    // Function row and space bar.
    for (x=[-27:9:27]) keycap(x,-9.0,7.0,4.0,1.05);
    keycap(-7.5,-45.3,24.0,3.8,1.0);
}

module keyboard_enter_key() {
    // Green enter key position, still part of the same paintable STL.
    keycap(15.15,-19.4,6.5,4.1,1.15);
}

module keyboard_keys() {
    keyboard_keys_grey();
    keyboard_enter_key();
}

module keyboard_front_lip() {
    translate([0,-48.9,0]) rounded_xz(76.0,7.2,2.2,2.0);
}

module keyboard_tabs() {
    for(x=keyboard_tab_x,z=keyboard_tab_z)
        // Start inside the rear face of the wedge so every tongue has a
        // positive-volume connection instead of only sharing a coplanar face.
        translate([x-keyboard_tab_w/2,keyboard_seam_y-0.8,z])
            cube([keyboard_tab_w,keyboard_tab_d,keyboard_tab_h]);
}

module keyboard_receiver_holes() {
    for(x=keyboard_tab_x,z=keyboard_tab_z)
        translate([x-keyboard_tab_w/2-keyboard_tab_clearance,
                   keyboard_seam_y-1.0,
                   z-keyboard_tab_clearance])
            cube([keyboard_tab_w+2*keyboard_tab_clearance,
                  keyboard_tab_d+1.4,
                  keyboard_tab_h+2*keyboard_tab_clearance]);
}

module hidden_keyboard_watermark() {
    // Enclosed inside the keyboard's solid front lip: three 0.20 mm layers.
    translate([0,-46.5,watermark_z]) linear_extrude(height=watermark_h)
        text(watermark_text,size=4.1,font="DejaVu Sans:style=Bold",
             halign="center",valign="center",spacing=1.05);
}

module keyboard_v05() {
    difference() {
        union() {
            // Remove the former 2.2 mm overlap with the front fascia. The
            // resulting visible seam is only the intentional assembly seam.
            intersection() {
                union() {
                    keyboard_wedge();
                    keyboard_keys();
                    keyboard_front_lip();
                }
                translate([-50,-60,-1])
                    cube([100,60+keyboard_seam_y,32]);
            }
            keyboard_tabs();
        }
        hidden_keyboard_watermark();
    }
}

module front_features() {
    // The front fascia extends 3.2 mm into the rounded cabinet. This is a
    // structural overlap, not a coplanar touch, and closes the former visible
    // slit between the CRT/front stack and the cabinet body.
    translate([0,3.2,0])
        rounded_xz(case_w-0.8,case_h-0.8,5.2,case_corner-0.4);

    // Convex CRT glass. Six nested profiles approximate the shallow compound
    // curve visible in the project avatar: the edge stays recessed while the
    // centre comes forward, but remains behind the beige bezel face.
    crt_screen_bulb();
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

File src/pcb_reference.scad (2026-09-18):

// Derived from iodeo/Minitel-ESP32 hardware Gerber v2.2, CC BY-SA 4.0.
// Source commit 39c49b8462b46dfb7da84c08aecdd48e5c52a224.
// Arc sampling <=0.08 mm, endpoint join tolerance 0.025 mm.
// Board thickness assumed 1.60 mm; component heights not defined.
pcb_reference_holes = [[16.60968, 1.59959], [-2.79084, 1.39893], [14.39226, 45.50603], [-9.70726, 42.40469], [-9.70726, 24.00493]];
module pcb_reference_outline_2d() {
polygon([[-5.40798, 20.60268], [-17.68804, 25.04859], [-17.75838, 25.07997], [-17.82427, 25.1199], [-17.88465, 25.16776], [-17.93857, 25.2228], [-17.98518, 25.28414], [-18.02376, 25.35083], [-18.0537, 25.42182], [-18.07452, 25.496], [-18.08591, 25.5722], [-18.08768, 25.64922], [-18.08768, 26.94976], [-18.01051, 26.95325], [-17.9343, 26.9659], [-17.86012, 26.98748], [-17.78902, 27.01769], [-17.722, 27.0561], [-17.65999, 27.10218], [-17.60387, 27.15527], [-17.55443, 27.21463], [-17.51236, 27.27942], [-17.47825, 27.34874], [-17.45259, 27.42161], [-17.43574, 27.497], [-17.42793, 27.57386], [-17.42926, 27.6511], [-17.43973, 27.72764], [-17.45919, 27.8024], [-17.48736, 27.87434], [-17.52384, 27.94243], [-17.56813, 28.00573], [-17.6196, 28.06334], [-17.67752, 28.11446], [-17.74109, 28.15836], [-17.8094, 28.19443], [-17.88151, 28.22216], [-17.95639, 28.24116], [-18.03299, 28.25116], [-18.11024, 28.25201], [-18.10798, 38.20516], [-18.02882, 38.2049], [-17.95065, 38.2183], [-17.87469, 38.2411], [-17.80207, 38.27296], [-17.73385, 38.3134], [-17.67105, 38.36183], [-17.61461, 38.41753], [-17.56534, 38.47968], [-17.52399, 38.54735], [-17.49117, 38.61954], [-17.46736, 38.69519], [-17.45292, 38.77317], [-17.44806, 38.85232], [-17.45286, 38.93148], [-17.46723, 39.00947], [-17.49097, 39.08514], [-17.52373, 39.15736], [-17.56502, 39.22507], [-17.61423, 39.28726], [-17.67063, 39.34301], [-17.73339, 39.39149], [-17.80157, 39.43199], [-17.87417, 39.46391], [-17.95011, 39.48677], [-18.02826, 39.50024], [-18.10747, 39.50411], [-18.10747, 40.80462], [-18.10569, 40.88162], [-18.09431, 40.95782], [-18.07348, 41.032], [-18.04355, 41.10299], [-18.00497, 41.16968], [-17.95835, 41.23102], [-17.90443, 41.28605], [-17.84406, 41.33391], [-17.77817, 41.37385], [-17.7078, 41.40523], [-5.42774, 45.85119], [-5.35878, 45.8741], [-5.28687, 45.88457], [-5.21424, 45.88226], [-5.14314, 45.86724], [-5.07578, 45.83999], [-5.01424, 45.80135], [-4.96043, 45.75251], [-4.90171, 45.70073], [-4.83481, 45.65973], [-4.76233, 45.62971], [-4.68604, 45.6114], [-4.60782, 45.60524], [-4.52961, 45.6114], [-4.45332, 45.62971], [-4.38084, 45.65974], [-4.31394, 45.70073], [-4.25428, 45.75168], [-4.20333, 45.81134], [-4.16233, 45.87823], [-4.13231, 45.95071], [-4.11399, 46.027], [-4.10783, 46.10522], [-4.10475, 46.18368], [-4.09552, 46.26165], [-4.0802, 46.33866], [-4.05888, 46.41423], [-4.03171, 46.4879], [-3.99883, 46.55921], [-3.96047, 46.62771], [-3.91685, 46.693], [-3.86823, 46.75466], [-3.81494, 46.81232], [-3.75728, 46.86562], [-3.69561, 46.91423], [-3.63033, 46.95785], [-3.56182, 46.99622], [-3.49051, 47.02909], [-3.41685, 47.05627], [-3.34127, 47.07758], [-3.26426, 47.0929], [-3.18629, 47.10213], [-3.10783, 47.10521], [17.09213, 47.10521], [17.1696, 47.10196], [17.24773, 47.0929], [17.32489, 47.07773], [17.40063, 47.05654], [17.47447, 47.02946], [17.54595, 46.99666], [17.61463, 46.95835], [17.68009, 46.91476], [17.74192, 46.86616], [17.79974, 46.81285], [17.8532, 46.75517], [17.90195, 46.69346], [17.94571, 46.62811], [17.98419, 46.55952], [18.01716, 46.48812], [18.04443, 46.41436], [18.06581, 46.33867], [18.08117, 46.26154], [18.09043, 46.18345], [18.09352, 46.10486], [18.11024, 1.00002], [18.10713, 0.92154], [18.0979, 0.84356], [18.08258, 0.76655], [18.06127, 0.69098], [18.03409, 0.61732], [18.00122, 0.54601], [17.96285, 0.4775], [17.91923, 0.41221], [17.87062, 0.35055], [17.81732, 0.29289], [17.75966, 0.23959], [17.698, 0.19098], [17.63271, 0.14736], [17.5642, 0.10899], [17.4929, 0.07612], [17.41923, 0.04894], [17.34366, 0.02763], [17.26665, 0.01231], [17.18867, 0.00308], [17.11021, 0.0], [16.91024, 3e-05], [-3.0898, 5e-05], [-3.16825, 0.00311], [-3.24623, 0.01234], [-3.32324, 0.02766], [-3.39881, 0.04897], [-3.47248, 0.07615], [-3.54379, 0.10902], [-3.61229, 0.14738], [-3.67758, 0.19101], [-3.73924, 0.23962], [-3.7969, 0.29292], [-3.8502, 0.35058], [-3.89881, 0.41224], [-3.94243, 0.47753], [-3.9808, 0.54603], [-4.01367, 0.61734], [-4.04085, 0.69101], [-4.06216, 0.76658], [-4.07748, 0.84359], [-4.08671, 0.92156], [-4.08979, 1.00002], [-4.08804, 20.3486], [-4.0942, 20.42681], [-4.11252, 20.5031], [-4.14255, 20.57558], [-4.18354, 20.64248], [-4.2345, 20.70214], [-4.29415, 20.75309], [-4.36105, 20.79408], [-4.43353, 20.8241], [-4.50982, 20.84242], [-4.58804, 20.84857], [-4.66625, 20.84242], [-4.74254, 20.82411], [-4.81502, 20.79408], [-4.88192, 20.75309], [-4.94158, 20.70214], [-4.99445, 20.65247], [-5.05599, 20.61382], [-5.12335, 20.58657], [-5.19445, 20.57156], [-5.26708, 20.56925], [-5.33899, 20.57971]]);
}
module pcb_reference_2d() { difference() {
pcb_reference_outline_2d();
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

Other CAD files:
archive/development/v0.5-rear-bay-fixture/stl/minitel_guide_coupon_v0.5-test.stl
archive/v0.1/minitel_front_v0.1.stl
src/render_reference.scad
archive/development/v0.5-rear-bay-fixture/src/minitel_v05_fit_test.scad
archive/development/v0.5-rear-bay-fixture/stl/minitel_rear_bay_v0.5-test.stl
archive/development/v0.5-rear-bay-fixture/stl/minitel_rear_retainer_v0.5-test.stl
archive/v0.1/minitel_accent_v0.1.stl
archive/v0.1/minitel_body_v0.1.stl
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

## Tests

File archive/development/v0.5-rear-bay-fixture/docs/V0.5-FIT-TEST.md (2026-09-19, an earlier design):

# v0.5 rear-bay fit test

v0.5 replaces the incompatible iodeo donor cassette with an open guide bay for
the owner's populated ESP Minitel V2 **JST** board. This is the physical fit
gate before the bay is incorporated into a complete Minitel-shaped body.

## Measured inputs

| Input | Value | Source |
|---|---:|---|
| PCB long dimension | 46.9 mm measured; 47.105 mm model | Owner measurement and v2.2 Gerber |
| PCB depth | 36.1 mm measured; 36.218 mm model | Owner measurement and v2.2 Gerber |
| Populated height | 10.4 mm | Bottom ESP32 module to top JST connector |
| USB-C outer edge to relaxed loop | 60.0 mm | Owner-selected routing envelope |
| PCB thickness | 1.60 mm | Nominal |

The visual cable reference is 5.0 mm in diameter because the cable diameter is
not measured yet. The fixture is open above the guide and therefore does not
trap a slightly larger cable.

## Mechanical layout

The connected JST end enters first from the open rear. The irregular nose and
connector pass between the guides. The broad USB-C edge then enters two flared
C-channels. Only about 1.0 mm of each bare PCB edge is carried; there is no
carrier plate, snap nub or mounting-hole pin.

The PCB ends with USB-C and RESET at the open rear. The connected cable turns
in front of the PCB and returns above the right guide. A removable retainer
slides downward after routing the cable. Its centre remains open, so the DIN
plug never has to pass through a printed hole. One narrow finger stops the PCB
from sliding backwards.

## Creality K2 print baseline

- 0.4 mm nozzle.
- 0.20 mm fixed layer height.
- 3 walls.
- PLA for the first fit test.
- No supports.
- No scaling or automatic hole compensation.
- Print each STL in its exported orientation.

The 1.6 mm PCB uses a 2.2 mm vertical slot: 0.30 mm clearance above and below.
The 47.105 mm Gerber width has 0.35 mm side clearance per side. The supporting
lip is 1.0 mm deep and remains printable with a 0.4 mm nozzle.

`WDTY v0.5` is enclosed in the front bridge as a 0.60 mm internal void. At the
0.20 mm baseline it occupies three layers, with three solid layers below and
three above. It is visible in slicer layer preview but not on the exterior.
Adaptive layer height changes the number of watermark layers.

## Test order

1. Print `minitel_guide_coupon_v0.5-test.stl` first.
2. Insert only the broad USB-C edge of the unpowered PCB. It should move with
   light finger pressure and without bending the board.
3. If the coupon passes, print `minitel_rear_bay_v0.5-test.stl` and
   `minitel_rear_retainer_v0.5-test.stl`.
4. Connect JST before insertion. Feed the PCB forward, form the relaxed cable
   turn, lay the return above the right guide and install the retainer from
   above.
5. Verify USB-C plug access and RESET operation while the board is unpowered.

Do not force a tight coupon. Report whether it is loose, correct, or tight and,
if possible, measure the printed slot and PCB thickness.

## CAD checks

- All three printable STLs have zero nonmanifold edges.
- The exact Gerber board plus the conservative 10.4 mm component envelopes were
  sampled at 49 positions over 48 mm of rearward travel, in 1 mm increments.
  No intersection with the fixture was found.
- The installed 5.0 mm cable reference has no intersection with the fixture.
- The installed retainer has no intersection with the PCB, component envelopes
  or cable reference.
- These checks validate the modelled envelopes. A physical coupon remains the
  authority for printer tolerance and unmeasured component placement.

Rebuild and verify from the repository root:

```sh
openscad --export-format binstl -D 'part="fixture"' -o stl/v0.5/minitel_rear_bay_v0.5-test.stl src/minitel_v05_fit_test.scad
openscad --export-format binstl -D 'part="coupon"' -o stl/v0.5/minitel_guide_coupon_v0.5-test.stl src/minitel_v05_fit_test.scad
openscad --export-format binstl -D 'part="retainer"' -o stl/v0.5/minitel_rear_retainer_v0.5-test.stl src/minitel_v05_fit_test.scad
python3 tools/check_v05_clearance.py
python3 tools/review_v05.py
```

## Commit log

2026-09-17 Publish experimental Mini Minitel case v0.1
    Add the parametric OpenSCAD source, printable STL parts, hardware reference photos, project avatar, documentation and CC BY-SA 4.0 attribution. This is an experimental first-fit prototype; proportion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
    [minitel_accent_v0.1.stl, minitel_assembly_v0.1.stl, minitel_body_v0.1.stl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]
2026-09-17 Add proportionally rebuilt v0.2 test prototype
    Add the deeper Minitel-style cabinet, extended fold-down keyboard, v0.2 printable meshes, fit-test instructions and proportion research notes. Keep v0.1 files for comparison.
    [minitel_accent_v0.2.stl, minitel_assembly_v0.2.stl, minitel_body_v0.2.stl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]
2026-09-17 Add v0.3 compatibility test parts and perspective renders
    Document the failed v0.2 PCB fit, preserve existing printed bodies with a corrective carrier, split the front for lower-support printing, and add a retained protruding reset plunger.
    [minitel_assembly_v0.3-test.stl, minitel_carrier_v0.3-test.stl, minitel_keyboard_v0.3-test.stl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]
2026-09-18 Update current docs and source paths after archiving prototypes
    [minitel_v03_compat.scad]
2026-09-18 Document archived prototype versions
2026-09-18 Add v0.3 assembly renders and Gerber-based PCB comparison
    Render the current assembly and carrier from actual meshes. Replace the rectangular PCB proxy in the README with an attributed Gerber-derived contour reference. Document the carrier mismatch; printable parts are unchanged and fit remains unverified.
    [pcb_reference.scad, pcb_reference.stl, render_reference.scad]
2026-09-18 Organize PCB reference model
    [pcb_reference.stl]
2026-09-18 Organize parametric source files
    [minitel_v03_compat.scad]
2026-09-18 Complete parametric source files
    [pcb_reference.scad, render_reference.scad]
2026-09-18 Organize v0.3 printable models
    [minitel_assembly_v0.3-test.stl, minitel_carrier_v0.3-test.stl, minitel_keyboard_v0.3-test.stl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]
2026-09-18 Remove obsolete root duplicate
    [minitel_assembly_v0.3-test.stl]
2026-09-19 Add v0.4 rear-entry review STLs
    [minitel_assembly_v0.4-review.stl, minitel_body_v0.4-review.stl, minitel_cover_v0.4-review.stl]
2026-09-19 Add unchanged iodeo enclosure reference meshes
    [box.stl, cover.stl]
2026-09-19 Add v0.4 rear-entry parametric source
    [minitel_v04.scad]
2026-09-19 Add front and rear v0.4 CAD renders
2026-09-19 Feature v0.4 review prototype with STL links and renders
2026-09-19 Archive v0.3 CAD source
    [minitel_v03_compat.scad]
2026-09-19 Archive v0.3 printable parts
    [minitel_assembly_v0.3-test.stl, minitel_carrier_v0.3-test.stl, minitel_keyboard_v0.3-test.stl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]
2026-09-19 Archive v0.4 prototype notes
2026-09-19 Archive v0.4 CAD source
    [minitel_v04.scad]
2026-09-19 Archive v0.4 printable parts
    [minitel_assembly_v0.4-review.stl, minitel_body_v0.4-review.stl, minitel_cover_v0.4-review.stl]
2026-09-19 Add v0.5 K2 fit test parts
    [minitel_guide_coupon_v0.5-test.stl, minitel_rear_bay_v0.5-test.stl, minitel_rear_retainer_v0.5-test.stl]
2026-09-19 Add v0.5 rear-bay CAD source
    [minitel_v05_fit_test.scad]
2026-09-19 Add complete two-part v0.5 case
    [minitel_case_v0.5.stl, minitel_esp32_bay_v0.5.stl]
2026-09-19 Add complete v0.5 CAD source
    [minitel_v05.scad]
2026-09-19 Archive intermediate v0.5 fixture source
    [minitel_v05_fit_test.scad]
2026-09-19 Archive intermediate v0.5 fixture STLs
    [minitel_guide_coupon_v0.5-test.stl, minitel_rear_bay_v0.5-test.stl, minitel_rear_retainer_v0.5-test.stl]
2026-09-19 Make complete v0.5 the current release
2026-09-20 Archive obsolete development file
    [minitel_v05_fit_test.scad]
2026-09-21 Refine v0.5 bay mechanics and measured fit
    Publish the measured 4.3 mm cable route, PCB latch, true U-rails, positive bay stop, regenerated STLs, validation updates and renders.
2026-09-21 Update v0.5 design and print instructions
    Document measured cable, DIN and reset dimensions plus the PCB latch and positive bay stop.
2026-09-21 Refine v0.5 bay CAD geometry
    Publish the complete v0.5 Minitel case and corrected ESP32 slide-in bay source.
    [minitel_v05.scad]
2026-09-21 Extend v0.5 mechanical validation
    Validate PCB insertion, cable routing, latch engagement and bay travel for the v0.5 print files.
2026-09-21 Publish refined v0.5 print files
    Upload the complete multicolor Minitel case and corrected U-rail ESP32 bay for Creality K2 test printing.
    [minitel_case_v0.5.stl, minitel_esp32_bay_v0.5.stl]
2026-09-21 Update v0.5 assembly and bay renders
    Show the corrected full assembly, loaded PCB bay and rear insertion route for v0.5.
2026-09-21 Document multicolor rear-down v0.5
    Describe the hollow cabinet, separate keyboard, fixed CRT front and three-part print workflow.
2026-09-21 Update v0.5 K2 print strategy
    Add rear-down case orientation, separate keyboard colors, hollow-shell bridging and revised assembly steps.
2026-09-21 Refactor v0.5 case and keyboard CAD
    Hollow the cabinet, join the CRT front structurally, add print bridge ribs and split out the keyboard.
    [minitel_v05.scad]
2026-09-21 Validate three-part v0.5 print design
    Check keyboard fit, hollow-case bay insertion, manifold meshes and generate the updated renders.
2026-09-21 Publish optimized three-part v0.5 STLs
    Add the hollow rear-down case and separate multicolor keyboard while retaining the validated ESP32 bay.
    [minitel_case_v0.5.stl, minitel_esp32_bay_v0.5.stl, minitel_keyboard_v0.5.stl]
2026-09-21 Add v0.5 hollow-case and keyboard renders
    Show the fixed CRT connection, hollow interior, bridge ribs and separate keyboard assembly.
2026-09-21 Focus README on current v0.5 design
    Remove obsolete pre-v0.5 walkthroughs and keep the project front page focused on current print files and instructions.
2026-09-21 Shape v0.5 CRT glass and recessed bezel
    Add a shallow compound CRT bulge and a funnel-shaped inner bezel while preserving the rear-down print orientation.
    [minitel_v05.scad]
2026-09-21 Publish convex CRT v0.5 case STL
    Replace the flat display face with the validated curved CRT and recessed bezel geometry.
    [minitel_case_v0.5.stl]
2026-09-21 Add convex CRT v0.5 renders
    Update the assembly views and add a close-up of the curved glass and inward-running bezel.
2026-09-21 Render curved v0.5 CRT detail
    Generate the updated assembly views and dedicated CRT close-up.
2026-09-21 Show the convex CRT v0.5 update
    Describe and preview the curved screen and inward-running bezel on the current design page.
2026-09-21 Refine v0.5 CRT bezel profile
    Use a narrow front rim, deeper tapered return, tighter corners and correctly position the status lens.
    [minitel_v05.scad]
2026-09-21 Publish refined v0.5 CRT case STL
    Update the printable case with the approved inward-running bezel and relocated status lens.
    [minitel_case_v0.5.stl]
2026-09-21 Update v0.5 renders for refined bezel
    Show the approved narrow rim, deeper inward taper and corrected status-lens position.
2026-09-21 Fix v0.5 USB-C service notch
    [minitel_v05.scad]
2026-09-21 Publish corrected v0.5 bay STL
    [minitel_esp32_bay_v0.5.stl]
2026-09-21 Publish corrected v0.5 USB-C bay STL
